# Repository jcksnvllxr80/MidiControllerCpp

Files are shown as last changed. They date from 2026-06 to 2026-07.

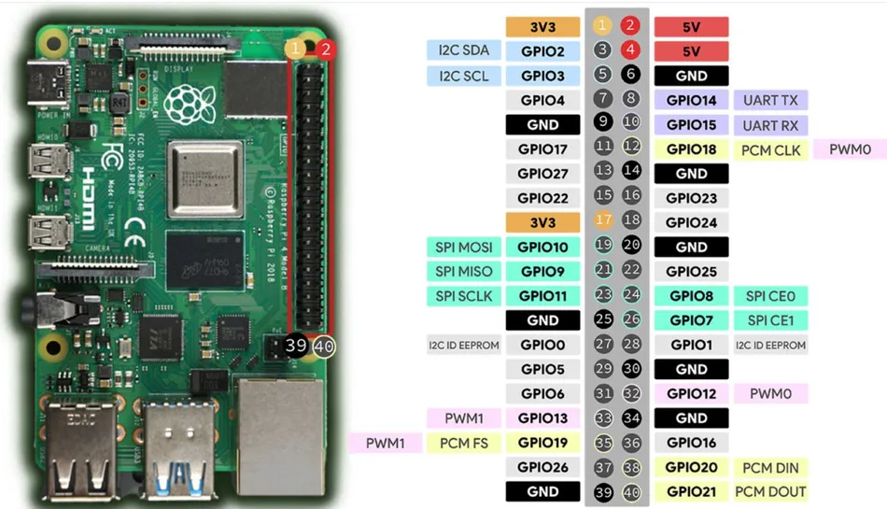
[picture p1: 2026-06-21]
docs/pi4_pinout.png

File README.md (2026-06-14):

# MidiController (C++)



Portable C++17 rewrite of a guitar-pedal MIDI controller's brain, ported from the
Raspberry Pi Python version. Hexagonal design: a hardware-free domain core with all
I/O behind interfaces, so the same code runs on the desktop sim now and a
microcontroller later.

Status: domain core + config + simulator are done and tested; the microcontroller
firmware (Pico 2 W / RP2350) builds and is under hardware bring-up. (The editor app
is a separate project.)
Roadmap: [docs/plan.md](docs/plan.md).

## Build, test, run (WSL)

The **firmware** builds with CMake + the Pico SDK; the **simulator** and the **tests**
build with `g++` (C++17) — GoogleTest and nlohmann/json are vendored, so the host
build has no other dependencies.

```sh
make build       # firmware  -> build-pico/midicontroller_pico.uf2  (Pico 2 W; needs PICO_SDK_PATH)
make build-sim   # simulator  -> build/midicontroller
make test        # build & run all tests (unit + mock + e2e)
make run         # run the simulator on data/ (scripted demo)
make clean       # remove desktop build/ ;  make pico-clean removes build-pico/
```

Flashing and wiring: [docs/mcu.md](docs/mcu.md) and [docs/wiring.md](docs/wiring.md).

## CI & releases

GitHub Actions ([`.github/workflows/ci.yml`](.github/workflows/ci.yml)) runs the host test
suite and builds the firmware `.uf2` on every push and PR. On a push to `master`, once both
pass, it cuts a GitHub **Release** `v<VERSION>` (from the [`VERSION`](VERSION) file) with the
versioned `.uf2` attached — **only when `VERSION` changed** (the tag is new). To ship: bump
`VERSION` and merge to `master`.

## Layout

```
include/mc/   headers: domain/ ports/ config/ adapters/ app/
src/          implementations + main.cpp
data/         config as JSON: midi_controller.json, pedals/, songs/, sets/
tests/        unit/ mock/ e2e/ support/
tools/        yaml2json.py (YAML→JSON), embed_data.py (bake data into flash), gen_font.py, gen_wiring_excalidraw.py
third_party/  vendored googletest + nlohmann/json
docs/         plan, architecture, domain, midi-protocol, config-format, mcu, wiring, wifi-app-handoff
```

## Notes

- The MIDI output matches the original Python byte-for-byte, including its quirks
  (e.g. `Set Preset`'s `cc:0` bank is never sent). See [docs/midi-protocol.md](docs/midi-protocol.md).
- `data/*.json` is generated from the original YAML by `tools/yaml2json.py` and committed.

## Docs

- [docs/architecture.md](docs/architecture.md) — ports & adapters + data-flow diagrams (mermaid)
- [docs/domain.md](docs/domain.md) — the core modules
- [docs/midi-protocol.md](docs/midi-protocol.md) — byte construction & dispatch
- [docs/config-format.md](docs/config-format.md) — JSON config reference
- [docs/mcu.md](docs/mcu.md) — firmware build/flash, adapters, hardware status
- [docs/wiring.md](docs/wiring.md) — Pico 2 W pin map, parts, power (+ `wiring.excalidraw` diagram)
- [docs/wifi-app-handoff.md](docs/wifi-app-handoff.md) — editor-app protocol contract (WiFi, device discovery, firmware update)

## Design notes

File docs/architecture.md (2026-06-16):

# Architecture

Ports & adapters (hexagonal). The domain core is pure C++ and depends only on
the **ports** (interfaces). Adapters implement the ports for a target; the
`Application` wires a concrete set of adapters to the core and runs the loop.

```mermaid
flowchart TB
    EXT["external editor (separate project)"] -- "USB / WiFi editor link" --> APP

    subgraph APP["app/ Application — composition root + event loop"]
      L["poll input → button/encoder handler → mutate state → display → emit MIDI"]
    end

    subgraph PORTS["ports/ (pure virtual HAL)"]
      direction LR
      IMidiOut & IDisplay & ILed
      IInput & IClock & IConfigStore & IConfigTransport
      IWifi & ISystemControl
    end

    subgraph SIM["adapters/sim (now)"]
      direction LR
      LMid["logging midi/led"] & CDisp["console display"]
      SInp["scripted input"] & CClk["chrono clock"] & FsCS["fs config store"]
    end

    subgraph MCU["adapters/mcu (Phase 3)"]
      direction LR
      EXP["MCP23017 footswitches (I²C) + encoder/LED GPIO"] & OLED["SSD1306 (SPI)"]
      DIN["MIDI → PIC bridge (I²C) → 6 jacks"] & STORE["FlashKv store + watchdog"]
      LINK["editor link: USB CDC + WiFi/mDNS :8080"]
    end

    subgraph CORE["domain/ (pure C++, no hardware, no JSON)"]
      direction LR
      MM["MidiMessage · Transform · Value"]
      PC["PedalConfig · MidiPedal"]
      SS["Setlist/Song/Part · ControllerState"]
      BM["ButtonSM · MenuTree"]
    end

    APP --> PORTS
    PORTS --- SIM
    PORTS --- MCU
    APP --> CORE
    CORE --> PORTS

    CFG["config/ConfigLoader\n(only JSON-aware module)"] --> CORE
    DATA[("data/*.json")] --> CFG
```

Data flow on a "load part":

```mermaid
sequenceDiagram
    autonumber
    participant U as Footswitch / Rotary (IInput)
    participant A as Application
    participant M as MenuTree
    participant P as MidiPedal (×N, channel order)
    participant Out as IMidiOut / IDisplay
    U->>A: InputEvent
    alt commit (Select / long-press / menu select)
        A->>P: turnOn/Off → setPreset → setParams
        P->>Out: exact CC/PC bytes
        A->>Out: song-info line
    else preview (Part/Song up/down)
        A->>Out: preview song-info line (no MIDI)
    else rotary
        A->>M: changeMenuPos / pressFor
        M->>Out: menu line
    end
```

> An `architecture.excalidraw` can be exported from the Mermaid above if a
> hand-editable canvas is wanted; the Mermaid here is the canonical source.

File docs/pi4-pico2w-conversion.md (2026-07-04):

# Pi 4 → Pico 2 W Conversion

The MidiController PCB is **unchanged**. This is a **driving-board swap**: the
Raspberry Pi 4 that used to plug into the board's 40-pin header (`J35`,
`Raspberry_Pi_2_3` in `PCB/MidiControllerPCB.sch`) is replaced by a Pico 2 W
(RP2350). The old ribbon now lands on a small adapter that routes each net to the
Pico GPIO below. **All wiring, buses, protocols, and the MCP23017 expander config
stay identical to the Pi** — the firmware just speaks the same three buses.

> **This supersedes an earlier draft of this doc that described a ground-up
> redesign** (native-GPIO footswitches, UART MIDI, an I²C OLED, a 6th footswitch,
> and "tempo pulse outputs"). None of that is on the real board — see the notes at
> the bottom.

## What actually crosses the ribbon

Only 14 signal lines (plus 3V3 / 5V / GND). Everything else lives behind the two
I²C peripherals on the board.

| Group | Signal | RPi 4 (BCM GPIO) | Pico 2 W (GP) | Goes to |
|---|---|---|---|---|
| **I²C bus** (shared) | SDA | GPIO2 | **GP4** | MCP23017 `0x22` + PIC `0x04` |
| | SCL | GPIO3 | **GP5** | same bus |
| **MCP interrupts** | INT A | GPIO4 | **GP2** | MCP23017 bank-A change |
| | INT B | GPIO17 | **GP3** | MCP23017 bank-B change |
| **OLED (SPI)** | SCLK | GPIO11 | **GP18** | SSD1306 |
| | MOSI | GPIO10 | **GP19** | SSD1306 |
| | CS | GPIO8 (CE0) | **GP17** | SSD1306 |
| | DC | GPIO12 | **GP20** | SSD1306 |
| | RST | GPIO25 | **GP21** | SSD1306 |
| **Rotary encoder** | Encoder A | GPIO24 | **GP14** | quadrature |
| | Encoder B | GPIO23 | **GP15** | quadrature |
| **RGB knob LED** | Red (PWM) | GPIO16 | **GP10** | knob LED |
| | Green (PWM) | GPIO20 | **GP11** | knob LED |
| | Blue (PWM) | GPIO21 | **GP12** | knob LED |
| **Power** | 3V3 | phys pin 17 | **3V3(OUT) pin 36** | net `VEE` → OLED supply (`J1`). (Pi pin 1, the other 3V3, is no-connect.) |
| | 5V | phys pin 2 | **VBUS pin 40** | net `VCC` → chip VDD + pull-ups — **see warning below** |

> ⚠️ **`VCC` (5 V) feeds more than "chip VDD + pull-ups" — it reaches six of
> the signal lines in the table above.** MCP23017 (`U2`) and the PIC bridge
> (`U10`) both run at `VCC` = 5 V, and so do: the I²C pull-ups (`R73`/`R74`
> on SDA/SCL), the MCP INT A/INT B push-pull outputs, and the rotary
> encoder's A/B pull-ups (`R29`/`R30`, confirmed in
> `pcb/midi-controller/MidiControllerPCB.net`). That means **GP4, GP5, GP2,
> GP3, GP14, GP15 all present 5 V to the Pico** and need level-shifting.
>
> **`VCC` stays at 5 V — it can't just be rewired to `3V3(OUT)`.** `U5` (a
> CD4050 hex buffer, powered from `VCC`) fans the PIC's MIDI output to all 6
> jacks, and MIDI's current-loop spec is nominally 5 V through 220 Ω
> resistors; dropping `VCC` to 3.3 V would weaken that drive for real MIDI
> gear. See [`wiring.md`](wiring.md) §1a for the level-shifter wiring (one
> 8-channel BSS138 module covers all 6 lines) and the full pin-by-pin
> breakdown. The encoder's RGB LED common is also tied to `VCC`,
> common-anode — not common-cathode as earlier drafts assumed.
| **Ground** (J35 GND pins) | GND | phys pin 6 | **GND pin 3** | board GND plane |
| | GND | phys pin 9 | **GND pin 8** | board GND plane |
| | GND | phys pin 14 | **GND pin 13** | board GND plane |
| | GND | phys pin 20 | **GND pin 18** | board GND plane |
| | GND | phys pin 25 | **GND pin 23** | board GND plane |
| | GND | phys pin 30 | **GND pin 28** | board GND plane |
| | GND | phys pin 34 | **GND pin 38** | board GND plane |
| | GND | phys pin 39 | **AGND pin 33** (tie to GND; ADC unused) | board GND plane |

The Pico-side assignments are the source of truth in
[`include/mc/adapters/mcu/Pins.h`](../include/mc/adapters/mcu/Pins.h); the BCM
column is what the adapter board maps each ribbon net **from**.

## What lives behind the buses (not on the ribbon)

- **5 footswitches + the rotary push button** are inputs on the **MCP23017 expander
  (`0x22`)**, read over I²C exactly as the Pi did (same IODIR/IPOL/GPINTEN/INTCON/
  GPPU/IOCON register values — see `McpExpander`). Expander bits: FSW1=A0, FSW2=A1,
  FSW3=A2, FSW4=B0, FSW5=B2, push button=B7 (the B7 selector is inverted via IPOL).
- **MIDI** is generated by writing raw bytes over I²C to the **PIC18F26K80 bridge
  (`0x04`)**, which fans every byte out to all **6 jacks: 2× DIN-5 + 4× TRS-MIDI**
  (`MIDI.py` did the same `writeRaw8`-per-byte). The Pico does **not** drive a MIDI
  UART, and the TRS jacks carry **MIDI**, not tempo.

## Key changes from the Pi

- **Form factor only.** The driver board changes (Pi 4 → Pico 2 W); the rest of the
  PCB, the expander, the PIC MIDI bridge, the OLED, the encoder, the LED, the
  footswitches, and all six MIDI jacks are untouched.
- The Pico has native USB for the editor link and on-board WiFi (CYW43); the Pi's
  network role is replaced by that.
- **The cooling fan is dropped.** It was driven by the Pi OS's temperature-based
  `gpio-fan` (set up in `raspi-config`), purely to cool the hot Pi 4 — not by the
  app, and not via any switching circuit on this PCB. The RP2350 runs cold and needs
  no active cooling, so there is no fan and no firmware fan control. Leave the `J2`
  fan header unpopulated.

## Corrections vs. the old "redesign" draft

For the record, so the redesign assumptions don't creep back in:

- **No 6th footswitch.** The board has 5 footswitches (plus the rotary push button).
- **No tempo/clock pulse outputs.** There is no GPIO-driven clock. The 4 TRS jacks are
  MIDI. Tempo on the Pi was set via menu/controls and is **display-only** (it was
  never even transmitted as MIDI — the only `TapTempo` reference was dead legacy code).
- **MIDI is over I²C to the PIC**, not native UART; **the OLED is SPI**, not I²C.

## Sources

- Pi 4: `MidiController/` — `Main/midi_controller.py`, `RotaryEncoder/RotaryEncoder.py`,
  `OledDisplay/OledDisplay.py`, `Footswitches/Footswitches.py`,
  `MCP23017_R1/MCP23017_R1.py`, `MIDI/MIDI.py`, `PCB/MidiControllerPCB.sch`
- PIC MIDI bridge: `MIDI_I2C_UART/` (I²C slave `0x04` → EUSART1 MIDI out)
- Pico 2 W: `include/mc/adapters/mcu/Pins.h`, `docs/wiring.md`

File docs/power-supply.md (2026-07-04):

# Power Supply — USB + Pedalboard 9V

The MIDI controller needs to run from two sources without conflict:

- **USB 5V** while programming/debugging the Pico from a PC.
- **Pedalboard 9V** (regulated down to 5V) during normal use on the board.

The Pico's power input is designed for exactly this. You don't switch between
sources — you OR them together so whichever is higher wins, with no
back-feeding.

## The Pico power pins

- **VBUS (pin 40)** — raw 5V straight from the USB connector.
- **VSYS (pin 39)** — main system input (1.8–5.5V). Feeds the onboard
  buck-boost SMPS that generates the 3.3V rail.
- On-board there is a **Schottky diode (D1) from VBUS → VSYS**. USB power
  reaches VSYS through ~0.3V of diode drop, but VSYS can never push current
  *back* into VBUS / the USB host.

That internal diode is the whole trick: mirror it for the external supply.

## Recommended circuit — two-diode OR into VSYS

```
   USB 5V ──[ internal D1 ]──┐
                             ├──► VSYS (pin 39) ──► SMPS ──► 3V3
9V→5V module ──[ ext Schottky ]─┘
                  │
   pedalboard GND ── common GND ── Pico GND (pin 38)
```

1. Regulate pedalboard **9V down to ~5V** with the module below.
2. Feed that 5V into **VSYS through a Schottky diode** (~0.3V drop, matches
   the internal D1).
3. Tie **grounds together** (pedalboard supply GND ↔ Pico GND).

VSYS then sits at roughly `max(VBUS − 0.3, Vext − 0.3)`. Whichever source is
higher powers the board; the lower one is reverse-blocked by its diode. USB can
be plugged in to program **while** the 9V is connected, with zero contention.

## The 9V → 5V module

**Breadboard: Recom R-78E5.0-1.0** — a synchronous buck regulator with the
inductor potted inside the package, so there's no separate magnetics part to
source or lay out. It's a **leaded, through-hole SIP-3 part** (TO-220-compatible
pin spacing, 2.54mm pitch) — plugs straight into a breadboard.

**PCB: MPM3610** — a synchronous buck regulator with the inductor built into
the package, so there's no separate magnetics part, no missing footprint to
chase down, and no FB-divider/inductor/extra-cap parts to place. It accepts up
to 21V in, comfortably covering the 9V pedalboard rail.

| Part | Breadboard | PCB |
|---|---|---|
| 9V→5V module | [Recom R-78E5.0-1.0](https://www.digikey.com/en/products/detail/recom-power/R-78E5-0-1-0/4930585) — SIP-3, THT, 5V/1A out, up to 28V in | [MPM3610GQV-Z](https://www.digikey.com/en/products/detail/monolithic-power-systems-inc/MPM3610GQV-Z/5292909) — QFN-20, 3×5×1.6mm, 5V/1.2A out, up to 21V in |
| OR-ing diode into VSYS | [1N5817-T](https://www.digikey.com/en/products/detail/diodes-incorporated/1N5817-T/22052) (DO-41, THT) | [SS14](https://www.digikey.com/en/products/detail/onsemi/SS14/965474) (SMA/DO-214AC) |

### PCB footprints (KiCad)

| Part | Package | KiCad footprint |
|---|---|---|
| MPM3610GQV-Z | QFN-20, 3×5×1.6mm | *No stock KiCad footprint* — download from [SnapEDA](https://www.snapeda.com/parts/MPM3610GQV-Z/MPS/view-part/) |
| SS14 diode | SMA / DO-214AC | `Diode_SMD:D_SMA` |

## Important details

- **Stay under 5.5V at VSYS.** 5V minus a Schottky drop ≈ 4.7V — well in
  range. Never feed 9V directly to VSYS.
- **Do NOT connect external 5V straight to VBUS.** That ties it to the USB 5V
  line and can back-feed the PC's USB port. Always enter via VSYS through the
  diode.
- **Pedalboard polarity:** many 9V pedal supplies are center-negative
  (Boss style) and daisy-chains can share ground unexpectedly. Ensure the
  module's input ground = output ground = Pico ground, and confirm jack
  polarity before wiring.
- **Current budget:** Pico + SPI OLED + MCP23017 (@0x22) + the I²C→MIDI PIC
  bridge (@0x04) is well under ~300mA — the MPM3610's 1.2A rating leaves
  plenty of headroom.

## Pedalboard Isolation (Strymon Ojai)

Audio noise on a pedalboard couples in through **shared ground and shared
supply**, not through the regulator topology. The Pico already has its own
switching SMPS onboard (the buck-boost making 3.3V), so the board is a
switching-noise source regardless of how the 5V is made. The defense is
**isolation**, and the supply for this build handles it:

- **Strymon Ojai** — five fixed **9V / 500 mA fully isolated** outputs off a
  24W brick (24V adapter). Each output is transformer-isolated, so its ground
  does **not** share copper with the audio pedals → no ground loop, no
  conducted hum path into the audio chain. (The 9-output **Zuma**, 48W, behaves
  identically if used instead.)
- **Use one dedicated isolated output** for the controller. **Do not
  daisy-chain** it with an audio pedal — keep them on separate windings.
- **Current:** controller draws ~300 mA → ~2.7W at the 9V input. Well under the
  500 mA per-output limit. Keep a running tally of all pedals so the board stays
  within the **24W total** budget.
- **Polarity:** Strymon outputs are **center-negative** 2.1mm barrel
  (Boss-standard). Wire the input jack as **tip = − / ground, sleeve = +9V**.
  Don't assume center-positive.

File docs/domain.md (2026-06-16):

# Domain model

The domain core is pure C++17 — no hardware, no JSON, no globals. Every module
maps to a piece of the original Python.

| C++ (`include/mc/domain`) | Ports from (Python) | Notes |
|---|---|---|
| `Value` | duck-typed `value` in EffectLoops | `variant<None, bool, long, string, EngagedRef>`. `EngagedRef{name, engaged}` is a song's `{name, engaged}` param value. |
| `MidiMessage` | `MIDI.py` | CC `[0xB0\|ch-1, cc, val]`, PC `[0xC0\|ch-1, prog]`. Channel→status math lives here, testable. |
| `Transform` | `EffectLoops.check_for_func` (`eval`) | Safe parser for `x <op> n` and `{...}.get(x, None)`. No `eval`. Unsupported expressions throw at load. |
| `PedalConfig` / `Action` | per-pedal YAML | Typed, recursive action tree. Group nodes (Engage, Set Preset, Knobs/Switches…) are the root `Action`'s children. |
| `MidiPedal` | `EffectLoops.MidiPedal` | `turnOn/Off`, `toggle`, `setPreset`, `setTempo`, `setParams`, `setSetting` + the dispatch (`determine_action_method` / `determine_parameter_method` / `convert_to_int` / `handle_multi`). Emits via `IMidiOut`. |
| `Setlist`/`Song`/`Part` | `PartSongSet.py` | Plain `std::vector` (the hand-rolled doubly-linked list is gone; prev/next is `index ± 1`). A `Part` holds, per pedal, `PedalState{engaged, preset, params, settings}`. |
| `ButtonSM` | `EffectLoops.ButtonOnPedalBoard` | Short (<0.5s) / long press; partner double-press (0.25s window). Time via `IClock`. |
| `ControllerState` | `midi_controller.yaml` | Current set/song/part, tempo, mode, knob colour/brightness, button lock, the channel→pedal table, the footswitch action map. |
| `MenuTree` | `N_Tree.py` + RotaryEncoder menu logic | The tree plus the rotary navigation engine and message formatting. Hardware-free: messages go to an injected sink, node behaviours are callbacks. |

## Deliberate differences from the Python

These are intentional, documented, and covered by tests.

- **Construction has no side effects.** Python's `MidiPedal.__init__` emitted
  engage + preset MIDI as a side effect of building the object. Here, building a
  pedal sends nothing; the `Application` drives every emission through
  `loadPart()`. Cleaner and deterministic.
- **Tempo is display-only, like the Pi.** The song BPM is shown on the OLED and
  never transmitted. Python *looked* like it sent tempo MIDI on part load, but only
  for a pedal named `TapTempo` — and no such pedal exists (legacy looper-era code),
  so it was dead. An early C++ draft added an `ITempoOut` pulse port for this; that
  was fiction (the board has no tempo jacks — the 4 TRS jacks are MIDI) and has been
  removed. `MidiPedal::setTempo()` remains as a faithful, unused mirror of the Python
  method.
- **No `eval`.** `Transform` is a fixed grammar; an unknown expression is a loud
  load-time error rather than a silently-evaluated lambda.
- **Menu select uses clean semantics.** The deep "edit a pedal's CC map" submenu
  (the densest, most device-specific Python) is not ported; the navigation engine
  that powered it *is*, and the Set/Song/Part/Knob/Lock menus are wired and
  tested.
- **Defaults persistence differs by target.** Python rewrote `midi_controller.yaml`
  on every part load. The firmware now does this too, but **debounced**: the current
  set/song/part are flushed via `Application::tick()` after ~1.5 s idle, so a flash
  write never lands mid-performance. The desktop sim deliberately does *not* persist,
  to avoid mutating the shared `data/` fixture.

See [`midi-protocol.md`](midi-protocol.md) for the byte-level dispatch and the
faithful quirks.

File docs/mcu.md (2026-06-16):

# Microcontroller target (Pico 2 W / RP2350)

Phase 3 adapters that run the same domain core on hardware. The desktop sim is
unchanged; only the adapters and the build system differ.

## Build & flash

Build the `.uf2` in WSL (same shell you run `make` in), then flash it to the
board. Because the repo lives on `C:\`, the built `.uf2` is also a normal Windows
file you can drag-and-drop.

### 1. One-time prerequisites (WSL / Ubuntu)

```sh
sudo apt update
sudo apt install -y cmake gcc-arm-none-eabi libnewlib-arm-none-eabi build-essential python3 git
# Pico SDK with pico2_w (RP2350) support — needs >= 2.1.0:
git clone --branch master --recurse-submodules https://github.com/raspberrypi/pico-sdk ~/pico-sdk
echo 'export PICO_SDK_PATH=$HOME/pico-sdk' >> ~/.bashrc && source ~/.bashrc
```

### 2. Build

```sh
cd /mnt/c/Users/A-A-Ron/git/MidiControllerCpp/MidiControllerCpp
cmake -B build-pico -DPICO_BOARD=pico2_w
cmake --build build-pico -j        # -> build-pico/midicontroller_pico.uf2
```
Or just **`make build`** from the repo root — it wraps the two commands above and
defaults `PICO_SDK_PATH` to `$HOME/pico-sdk` (override: `make build PICO_SDK_PATH=...`).
(`make build-sim` builds the desktop simulator instead; `make pico-clean` wipes `build-pico/`.)
The editor link (and debug output) run over the USB CDC automatically — no flag
needed. WiFi (CYW43 + lwIP + mDNS) is built in too (the board is `pico2_w`).
CMake runs `tools/embed_data.py` (needs Python 3) to bake `data/*.json` into flash;
exceptions are enabled (`PICO_CXX_ENABLE_EXCEPTIONS`) because the loader throws on bad
config — and `Application::setup()` catches that and falls back to a safe, still-reachable
shell so a corrupt config can't brick boot.

### 3. Flash

> **First flash on a fresh Pico 2 W: you must use the BOOTSEL button.** A blank board has
> no firmware yet to accept a software "reboot to bootloader", so the hardware bootloader
> (hold **BOOTSEL** while power-cycling) is the only way in the first time.

**BOOTSEL drag-and-drop (easiest on Windows):**

1. Hold the **BOOTSEL** button while plugging the Pico into USB (i.e. power-cycle it with
   the button held). It mounts as a drive named **RP2350**.
2. Drag `...\MidiControllerCpp\build-pico\midicontroller_pico.uf2` onto that drive
   in Explorer (or `cp build-pico/midicontroller_pico.uf2 /mnt/e/` to the drive
   letter it mounted as). It reboots and runs immediately.

**Alternative — picotool** (run on Windows; WSL needs `usbipd` USB pass-through):
```sh
picotool load -x build-pico/midicontroller_pico.uf2   # -x = run after loading
```

**After the first flash — no button needed.** Once this firmware is on the board it can
drop itself into BOOTSEL on command: send `{"op":"reboot_bootloader"}` over USB or WiFi and
it re-enumerates as the `RP2350` drive, then copy the `.uf2` as above. The editor app
(**MidiControllerControllerApp**, the separate UI repo) drives this from a button — see
[`wifi-app-handoff.md`](wifi-app-handoff.md) (Task 4) for the end-to-end update flow.

### 4. Connect / debug

The device enumerates as a USB serial port named **"MidiController"**. Both the
editor protocol and debug `printf` share that one CDC (the app's codec skips
non-JSON noise). Open the COM port at 115200 to watch traffic or talk to it
directly. The editor app connects via its **Serial** transport (not the USB-raw
one, which is a stub for CDC devices).

> Wire your hardware to match `include/mc/adapters/mcu/Pins.h`. See
> [`wiring.md`](wiring.md) for the full build — pin map, external parts, power, and a
> diagram ([`wiring.excalidraw`](wiring.excalidraw)). The build compiles clean and the
> **USB editor link is confirmed working on hardware** (over serial). **WiFi is
> compile-verified only** — not yet tested on a real network.

## Adapters (`include|src/adapters/mcu/`)

| Adapter | Port | Notes |
|---|---|---|
| `McuClock` | IClock | `time_us_64()` |
| `McuMidiOut` | IMidiOut | raw MIDI bytes over I2C to the PIC bridge @0x04 (writeRaw8 per byte); the PIC fans out to all 6 jacks |
| `McpExpander` | (helper) | MCP23017 @0x22 over I2C; configured byte-for-byte like the Pi (Footswitches.py); supplies the switch inputs |
| `McuLed` | ILed | 3-channel PWM; colour names match RgbKnob |
| `McuInput` | IInput | 5 footswitches + rotary push button read from `McpExpander` over I2C (INT-driven, reuses domain `ButtonSM`); quadrature encoder on native GPIO |
| `Ssd1306Display` | IDisplay | 128x64 SSD1306 over SPI (7-pin header: SCLK/MOSI/CS/DC/RST + power/GND); splits on " - " into rows |
| `McuConfigStore` | IConfigStore | reads config baked into flash; writes go to a RAM overlay, persisted via `FlashKv` |
| `FlashKv` | (persistence) | stores the write overlay in one reserved flash sector (`KvCodec`, host-tested) |
| `EditorProtocol` (app) | — | newline-JSON request/response; shared by the USB and WiFi links |
| `StdioConfigTransport` | IConfigTransport | runs `EditorProtocol` over the USB CDC |
| `WifiManager` | IWifi | CYW43 STA join, lwIP TCP server (same protocol) on `:8080`, mDNS, creds in flash |
| `McuSystemControl` | ISystemControl | `reboot` (app) / `reboot_bootloader` (USB BOOTSEL via `reset_usb_boot`); reset deferred so the editor ack flushes first |

Pin assignments live in one place: `include/mc/adapters/mcu/Pins.h` — edit to match your
wiring. The full build (pin map, external parts, power, diagram) is in [`wiring.md`](wiring.md).

## Status of the hardware-only pieces

These can't be compiled/flashed without the SDK + board, so they're marked by how
far they're verified:

- **OLED font** — DONE. Full ASCII 0x20–0x7E in `Ssd1306Font.h`, generated by
  `tools/gen_font.py` from the public-domain Adafruit GLCD font.
- **USB editor link** — DONE and **confirmed working on hardware** (over serial):
  `identify`/`ping`/`list_*`/`get_*`/`write_*`/`dpad`/`short`, plus `delete_set`/
  `delete_song`/`delete_pedal`/`delete_part` and `write_part` (via the new
  `IConfigStore::remove`; the flash store tombstones build-time-embedded entries
  since their blobs can't be erased). `write_part`/`delete_part` read-modify-write
  the song file (parts have no file of their own). Also `reboot_bootloader` (drops
  into USB BOOTSEL via `reset_usb_boot` — flash a `.uf2` with no front button) and
  `reboot`, both behind `ISystemControl`/`McuSystemControl` (the reset is deferred a
  few ms so the ack flushes first). `identify` now also returns a `device_id` (the
  RP2350 board id) so the editor can dedupe one unit seen over both USB and WiFi.
  A second **raw-USB** path was added (`-DMC_ENABLE_USB_EDITOR=ON`): a vendor-class
  interface (`usb/usb_descriptors.c` + `UsbConfigTransport`, bulk IN/OUT) with
  MS-OS-2.0 descriptors so Windows auto-binds **WinUSB**, for the host app's `nusb`
  transport. **Unverified on hardware** (the verified link is the default CDC build;
  select this variant with `-DMC_ENABLE_USB_EDITOR=ON`). Must match host
  `transport/usb.rs`: VID 0xCAFE/PID 0x4001, iface 0, EP OUT 0x01 / IN 0x81; stdio
  moves to UART in that build.
- **Flash persistence** — DONE (codec host-tested) and in use: WiFi creds *and* the
  "save defaults" (current set/song/part, written back debounced on change) persist
  via `FlashKv`. Erase/program now goes through `flash_safe_execute()` (XIP-safe;
  `PICO_FLASH_ASSUME_CORE1_SAFE=1` since core1 is never launched — falls back to an
  IRQ-masked write if the safe path is unavailable). Still one reserved 4 KB sector;
  large multi-file edits are a multi-sector follow-up.
- **Reliability** — DONE: an 8 s hardware **watchdog** (enabled after boot init, fed
  each main-loop pass) reboots on a hang; `Application::setup()` falls back to a safe
  shell on bad config; the WiFi connect/reconnect is non-blocking so it can't stall
  the loop under the watchdog; "save defaults" is debounced (1.5 s idle) so a part
  change mid-song doesn't fire an IRQ-masked flash write.
- **WiFi** — built and **compile-verified only (not network-tested)**. First-time
  setup is over USB (`wifi_set`); on boot it auto-joins the saved network
  (non-blocking) and **auto-reconnects** if the link drops, serves the same protocol
  over TCP `:8080`, and advertises via mDNS (`midicontroller.local` /
  `_midicontroller._tcp`). On/off via `wifi_enable`. The app side (a WiFi transport +
  "Set WiFi" UI) is specced in [`wifi-app-handoff.md`](wifi-app-handoff.md).
- **MCP23017 input + selector polarity** — the expander is configured exactly as the
  Pi did (`McpExpander`), but the INT-triggered read path and the selector's
  inverted-polarity decode are **compile-verified only** — confirm
  on hardware that all 5 footswitches and the rotary push button register.
- **MIDI over I2C** — bytes go to the PIC @0x04 like the Pi; **confirm on hardware**
  the bridge still fans out to the DIN + TRS jacks.
- **OLED over SPI** — transport rewritten from I2C to SPI (7-pin header); **confirm on hardware**.
- **On-target RAM check** — confirm the peak by parsing `BigSky.json` on device.

## Why RP2350 / Pico 2 W

520 KB RAM (vs RP2040's 264 KB) is what lets the build keep nlohmann/json
uncompromised: config is parsed one file at a time, peak is the largest pedal's
JSON DOM (~hundreds of KB worst case) which the 2 W absorbs comfortably. PIO,
dual M33 + FPU, and native USB cover MIDI timing and the host link.
Confirm the real RAM peak by parsing BigSky on-target once.

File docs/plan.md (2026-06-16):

# MidiController: Python → C++ Port

> **Hardware-model correction (supersedes parts of this roadmap).** This plan was
> written assuming a redesign that turned out not to match the real, fixed PCB. The
> truth, verified against the schematic and the Python source: **5 footswitches**
> (not 6) + a rotary push button, all on an **MCP23017 expander over I²C**; **MIDI
> goes over I²C to a PIC bridge (`0x04`)** that fans out to 6 jacks (2× DIN-5 +
> 4× TRS-MIDI — all MIDI, **no tempo jacks**); the **OLED is on SPI**. There is **no
> `ITempoOut`/tempo-pulse port** — tempo is display-only. The Pico 2 W is a
> **driving-board swap** onto the unchanged PCB. See
> [`pi4-pico2w-conversion.md`](pi4-pico2w-conversion.md) and [`wiring.md`](wiring.md);
> phase bullets below that mention "6 footswitches", "4 tempo outputs", `ITempoOut`,
> "native MIDI DIN", or "tap tempo" are obsolete.

## Context
The guitar pedal runs as Python on a Raspberry Pi 4: **5 footswitches**, an OLED, a rotary
knob (RGB LED + pushbutton), and MIDI out. The Pi is the "brain" (UI, song/preset state,
MIDI message building); the switches/push button are on an **MCP23017 expander (I²C)** and
a **PIC bridge (I²C `0x04`)** turns the Pi's MIDI bytes into the physical jacks (2× DIN-5 +
4× TRS-MIDI). A Java HTTP bridge (`piMidiHttp`) + a web app edit config files over WiFi.

Goal now: rewrite the **brain** in clean, portable C++ so it can later move to a
microcontroller (WiFi → USB). Get the C++ patterns right and fully tested first; hardware
comes later. This plan covers the firmware only; the controller/editor app is a separate project.

## Decisions (locked)
- **Firmware lives in** `C:\Users\A-A-Ron\git\MidiControllerCpp\MidiControllerCpp`. The controller/editor app is a separate project, out of scope here.
- **Config format: JSON.** One-time convert the existing YAML songs/sets/pedals to JSON.
- **Build/run: WSL + GoogleTest, plain Makefile.** Host: `make build-sim` / `make test` / `make run` (only needs `g++`). Firmware: `make build` → the Pico `.uf2` (needs the Pico SDK). Phase 1 had no real hardware — desktop/sim adapters only.
- **Architecture: ports & adapters (hexagonal).** Pure C++ domain core; all hardware behind interfaces. Same core runs on the sim now and the microcontroller later.
- **This plan is maintained in-repo** at `MidiControllerCpp/docs/plan.md` as the canonical, living roadmap — updated as each phase lands. The `~/.claude/plans/` copy is throwaway.

## Status (updated 2026-06-14)
- **Phase 1 — DONE.** Domain core (`MidiMessage`, `Value`, `Transform`, `PedalConfig`,
  `MidiPedal`, `Setlist/Song/Part`, `ButtonSM`, `ControllerState`, `MenuTree`), all 8
  ports, JSON config loaders, and the one-shot `tools/yaml2json.py` → committed `data/*.json`.
- **Phase 2 — DONE.** Sim adapters (`adapters/sim`), the `Application` event loop + `main.cpp`,
  and docs (`README.md` + `docs/{architecture,domain,midi-protocol,config-format}.md`).
- **Tests — ~850 passing** (unit + mock + e2e) via vendored GoogleTest/GoogleMock; `make build-sim`/`test`/`run`
  all green in WSL, zero warnings. Verification criteria 1–4 below are met. Coverage: a data-driven
  suite checks every reachable pedal param (representative values) through the real dispatch, plus
  per-module suites for MidiMessage/Value/Transform/PedalConfig/MidiPedal/SongPartSet/ControllerState/
  ButtonSM/MenuTree/ConfigLoader/FsConfigStore/sim adapters/Application, and per-part e2e flows.
- **Faithful-port decision:** observable MIDI is reproduced byte-for-byte, including the Python
  quirks (notably `Set Preset`'s `bank` uses `cc:0`, falsy in Python → bank select never sent;
  only the preset Program Change goes out). Documented in `docs/midi-protocol.md` and locked by tests.
- **Phase 3 (mcu) — builds clean, under hardware bring-up.** Target board: **Pico 2 W (RP2350)**.
  `adapters/mcu/` + the Pico `CMakeLists.txt` + `tools/embed_data.py` build a ~1.5 MB `.uf2` (`make build`);
  the core is MCU-ready (`Transform`'s `std::regex` is a hand parser; nlohmann/json is kept — the RP2350's
  520 KB RAM affords it). All adapters, WiFi (CYW43 + lwIP + mDNS) with non-blocking auto-reconnect,
  `FlashKv` persistence via `flash_safe_execute`, an 8 s watchdog, a boot-config guard, debounced
  "save defaults", the full OLED font, and the editor protocol (incl. `delete_*`/`write_part`,
  `reboot`/`reboot_bootloader`, `device_id`) are **compile/link-verified**. The **USB serial editor
  link is confirmed on hardware**; WiFi and the physical I/O are not yet bench-tested. See `docs/mcu.md`.

## What it does (so the model is clear)
Data model: **Setlist → Songs → Parts**. A Part stores, per pedal, `(engaged, preset, params, settings)`. Loading a Part sends MIDI to set every pedal's on/off + preset (+ tempo). A **MidiPedal** has a name, a MIDI channel (1–16), and a per-pedal command map that turns high-level actions (Engage, Bypass, Set Preset, Set Tempo, knob/param tweaks) into MIDI CC/PC bytes. Footswitches step parts/songs; the rotary knob drives a menu for editing.

## Architecture
```
        USB IConfigTransport  (external editor — separate project)
                 │
        ┌────────▼─────────┐
        │   Ports (HAL)    │  IMidiOut IDisplay ILed
        │   interfaces     │  IInput IClock IConfigStore IConfigTransport
        └───┬──────────┬───┘
   adapters │          │ adapters
   ┌────────▼───┐  ┌───▼──────────┐
   │ sim/desktop│  │ mcu (Phase3) │
   └────────────┘  └──────────────┘
        ▲
   ┌────┴───────────────────────────────────┐
   │ Domain core (pure C++, no hardware)     │
   │ MidiPedal · Transform · Setlist/Song/   │
   │ Part · ControllerState · ButtonSM ·     │
   │ MenuTree · MidiMessage                  │
   └─────────────────────────────────────────┘
```

## Target layout (`MidiControllerCpp/`)
```
include/           public headers (mirror src)
src/
  domain/          MidiMessage, MidiPedal, PedalConfig, Transform,
                   Setlist/Song/Part, ControllerState, ButtonSM, MenuTree
  ports/           IMidiOut, IDisplay, ILed, IInput, IClock, IConfigStore,
                   IConfigTransport, IWifi, ISystemControl  (pure virtual)
  config/          JSON loaders -> domain objects
  adapters/sim/    console display, scripted input, fs config store, chrono clock, logging midi
  adapters/mcu/    Pico 2 W: MCP23017 footswitches (I²C), SPI OLED, I²C MIDI bridge, encoder+LED GPIO, FlashKv, WiFi, USB editor link
  app/             Application (composition root + event loop)
  main.cpp
data/              converted JSON: midi_controller.json, songs/, sets/, pedals/
tests/             unit/, mock/, e2e/ + fixtures
docs/              plan.md (this roadmap), architecture.md (mermaid), domain.md, midi-protocol.md,
                   config-format.md, mcu.md, wiring.md (+ wiring.excalidraw), wifi-app-handoff.md
third_party/googletest   (vendored submodule, built by Makefile)
tools/             yaml2json.py (YAML→JSON), embed_data.py (bake → flash), gen_font.py, gen_wiring_excalidraw.py
Makefile
```

## ~~Phase 1 — Domain core + config (the actual conversion)~~ ✅ done
Build the pure-C++ core. Python source → C++ target:

| C++ module | Ports from | Notes |
|---|---|---|
| `MidiMessage` | `MIDI.py` | Builds CC `[0xB0|ch-1, cc, val]` / PC `[0xC0|ch-1, prog]`. Channel→status math lives here (testable), not in the adapter. |
| `Transform` | `EffectLoops.check_for_func` (`eval('lambda x: ...')`) | Replace `eval` with a tiny safe parser for `x <op> n`, op ∈ `+ - * / %`. Covers the only real cases (`x / 128`, `x % 128`). |
| `PedalConfig` | per-pedal YAML (`TimeLine.yaml`…) | Parsed map: Engage/Bypass/Toggle/Set Preset/Set Tempo/Knobs-Switches/Parameters. Each action = cc|pc|multi + optional transform, `dict` (name→int), `min`/`max`, `on`/`off`. |
| `MidiPedal` | `EffectLoops.MidiPedal` | `turnOn/Off`, `toggle`, `setPreset`, `setTempo`, `setParam(s)`, `setSetting`. Same dispatch as `determine_action_method` / `convert_to_int` / `handle_multi_functions`. |
| `Setlist/Song/Part` | `PartSongSet.py` | Plain `std::vector` (drop the hand-rolled doubly-linked list; keep prev/next via index). Part = `map<pedalName, PedalState>`. |
| `ButtonSM` | `EffectLoops.ButtonOnPedalBoard` | Short (<0.5s)/long press; partner double-press 0.25s window. Time via `IClock` so it's testable. |
| `ControllerState` | `midi_controller.yaml` | current setlist/song/part, tempo, mode, knob color/brightness, buttons_locked. |
| `MenuTree` | `N_Tree.py` + `RotaryEncoder.py` menu logic | The messiest port. Rotary CW/CCW navigation + select/long-hold thresholds. Port the tree + actions; isolate from hardware. |
| `config/*` | `setup()` in `midi_controller.py` | Load JSON → build pedals/state/songs. |

Ports defined this phase (headers only, sim impls in Phase 2): `IMidiOut`,
`IDisplay`, `ILed`, `IInput`, `IClock`, `IConfigStore`, `IConfigTransport`.

Data: run `tools/yaml2json.py` once to convert all existing YAML (songs, sets, pedals,
`midi_controller.yaml`) into `data/*.json`; commit the JSON. JSON lib: vendor a single
header (e.g. `nlohmann/json`) now; swap to a tiny MCU-friendly parser in Phase 3.

## ~~Phase 2 — Simulator, event loop, e2e, docs~~ ✅ done
- **Sim adapters** (`adapters/sim/`): console/stdout display, scripted-or-keyboard input, `std::filesystem` config store, `std::chrono` clock, a MIDI adapter that logs messages.
- **Application** (`app/`): wires ports+adapters and runs the event loop — port of `main()`/`setup()`. Poll input → button/encoder handler → mutate state → update display → emit MIDI. Replaces the Flask loop.
- *(An early draft added an `ITempoOut` pulse port here; it was later removed — the board has no tempo jacks and tempo is display-only. See the banner at the top.)*
- **Docs**: `architecture.excalidraw` (the diagram above), root `README.md` (build/test + layout, mermaid sequence of the event loop), short `domain.md`, `midi-protocol.md`, `config-format.md`. Concise — only what must be understood.

## Phase 3 — Microcontroller (in progress — Pico 2 W / RP2350)
Swap in `adapters/mcu/` to drive the **unchanged PCB** (driving-board swap, not a redesign): MCP23017 footswitches + rotary push button over I²C (`McpExpander`), native-GPIO encoder/LED, SSD1306 over **SPI**, MIDI as raw bytes over **I²C to the PIC bridge `0x04`** (which fans out to the 6 jacks), flash `IConfigStore`, and **USB `IConfigTransport`**. Core and tests stay unchanged — that's the payoff of the HAL.

Done (compile/link-verified, `make build` → `.uf2`): all adapters (`McuClock/McuMidiOut/McpExpander/McuLed/McuInput/Ssd1306Display/McuConfigStore/FlashKv/StdioConfigTransport`), `Pins.h`, `main_mcu.cpp`, the Pico `CMakeLists.txt` (board `pico2_w`, exceptions on), and `tools/embed_data.py`. Added beyond the original scaffold: **WiFi** (`WifiManager` — CYW43 STA + lwIP TCP `:8080` + mDNS, the same `EditorProtocol`, non-blocking auto-reconnect), the full OLED font (`tools/gen_font.py`), `FlashKv` persistence via `flash_safe_execute` (WiFi creds + debounced "save defaults"), an 8 s **watchdog**, a boot-config guard, editor-protocol `delete_*`/`write_part` + `reboot`/`reboot_bootloader` + `device_id` (`ISystemControl`/`McuSystemControl`), and the raw-USB/WinUSB link (`-DMC_ENABLE_USB_EDITOR`). `std::regex` removed from `Transform`. The desktop Makefile excludes `src/adapters/mcu/`; SDK-free MCU logic (codec, config store) is host-tested.

TODO before it ships: bench-test the physical I/O (MCP23017 footswitches + selector polarity, encoder, SPI OLED, I²C MIDI to the PIC, LED) and WiFi on a real board; an on-target RAM check parsing BigSky; the deferred on-device features (deep "Midi Pedals" editor menu, favourite mode, footswitch partner combos, About/IP screen); and a deliberate later pass on WiFi at-rest cred scrambling + wire auth/TLS. See `docs/mcu.md`.

## Tests (GoogleTest / GoogleMock)
- **Unit** (`tests/unit/`): `Transform` parse+eval; `MidiMessage` byte exactness; `convert_to_int`/dict/min-max/on-off; Setlist/Song/Part JSON load; `ButtonSM` short/long/partner with a fake clock; `MenuTree` navigation; config loaders.
- **Mock** (`tests/mock/`): `MidiPedal` against `MockMidiOut` — assert the **exact** CC/PC byte sequence for engage/bypass/preset (incl. `multi` bank+preset = `x/128` then `x%128`)/tempo/param. `ButtonSM` against `MockClock`. `Application` against mock display/input — assert display text.
- **E2E** (`tests/e2e/`): drive `Application` with scripted input + fake clock + the **converted real** fixtures (a setlist with real pedals). Assert the MIDI output sequence and display messages across: load setlist → next/prev part → next song → menu edit. This is the in-process equivalent of the old Flask `short`/`long`/`dpad` endpoints.

## Build (Makefile, run in WSL)
- `make build` — build the Pico firmware `.uf2` (CMake + Pico SDK; see `docs/mcu.md`).
- `make build-sim` — compile core + sim into a `midicontroller` binary.
- `make test` — build & run all GoogleTest suites (gtest/gmock compiled from vendored `third_party/googletest`).
- `make run` — launch the sim.
- `make clean` / `make pico-clean` — remove the desktop `build/` / firmware `build-pico/` artifacts.
Toolchain: `g++` (C++17), no apt deps beyond a compiler — googletest and the JSON header are vendored.

## Key risks / explicit decisions
- **`eval` → `Transform`**: arbitrary Python lambdas become a fixed safe grammar. If a pedal config ever needs an unsupported expression, the loader errors loudly rather than guessing.
- **Menu tree** is the densest Python logic — port it behind tests first, with `MenuTree` fully hardware-free.
- **MIDI channel math** stays in the domain so output is verifiable without hardware.
- **MIDI on the MCU** goes over I²C to the PIC bridge (`0x04`), paced at the MIDI byte rate so the bridge's 8-byte UART FIFO can't overrun. (Tempo is display-only — there is no tempo-output port; see the banner.)

## Verification
1. `make build-sim` succeeds in WSL.
2. `make test` — all unit/mock/e2e suites green; mock tests prove exact MIDI bytes match the Python behavior for real pedal configs.
3. `make run` — sim boots from `data/`, scripted footswitch/encoder input changes parts/songs and logs the expected MIDI + display text.
4. Spot-check: converted `data/*.json` round-trips the same pedal/preset/tempo state the Pi used (`midi_controller.yaml` → `midi_controller.json`).

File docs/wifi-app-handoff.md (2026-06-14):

# Handoff: add WiFi support to the controller app

**Audience:** an agent working in `MidiControllerControllerApp` (Tauri + Svelte UI,
Rust backend). The **firmware** WiFi side is done (see this repo); the app needs a
matching **WiFi transport** + a **"Set WiFi" UI**. The wire protocol is unchanged —
WiFi carries the exact same newline-JSON the serial transport already speaks, so
you reuse `protocol/codec.rs` verbatim.

## What the firmware already does

- Stores WiFi credentials in flash; on boot, if enabled, joins the saved network
  (non-blocking) and **auto-reconnects** if the link later drops — no reboot needed,
  so the app's TCP transport should simply retry the connection after a blip.
- Runs the **same** request/response protocol over **TCP on port 8080** (in
  addition to USB serial).
- Advertises via **mDNS**: hostname `midicontroller.local`, service
  `_midicontroller._tcp` on port 8080, TXT `version=1`.
- Adds three ops (work over USB *and* TCP):

  ```jsonc
  // set credentials (first-time setup, done over USB) — enables WiFi + connects
  -> {"id":N,"op":"wifi_set","ssid":"MyNet","password":"secret"}   // password optional (open net)
  <- {"id":N,"ok":true,"data":{"enabled":true,"connected":true,"ssid":"MyNet","ip":"192.168.1.50"}}

  // query status
  -> {"id":N,"op":"wifi_status"}
  <- {"id":N,"ok":true,"data":{"enabled":bool,"connected":bool,"ssid":"...","ip":"..."}}

  // turn WiFi on/off (persisted)
  -> {"id":N,"op":"wifi_enable","on":false}
  <- {"id":N,"ok":true,"data":{...status...}}
  ```

## First-time setup flow (UX)

1. User connects over **USB/Serial** (already works).
2. App shows a **"WiFi" screen**: SSID + password fields → on save, send `wifi_set`.
3. Show the returned `ip` (the OLED shows it too). Device is now on the network.
4. Next launch (or after a rescan), the **WiFi transport discovers it via mDNS**
   and the user can connect wirelessly — no cable.

## Firmware protocol contract (what's actually implemented)

So you don't have to infer it from the firmware source — this is exactly how the
device behaves, on **both** the USB serial link and the WiFi TCP link (identical
framing).

**Framing**
- One JSON object per line, `\n`-terminated. Requests carry an `id`; the firmware
  echoes it in the response.
- Success: `{"id":N,"ok":true,"data":<op-specific>}` (no `error`). `data` is
  omitted for ops that have no payload.
- Failure: `{"id":N,"ok":false,"error":"<message>"}` (no `data`).
- The firmware **ignores blank / non-JSON lines** (debug `printf` shares the same
  USB CDC), so a reader must skip non-matching lines — exactly what `codec.rs`
  already does.
- USB: 115200 8N1, device product string "MidiController". WiFi: TCP `:8080`,
  **one client at a time**. Same JSON framing on both.

**Ops the firmware answers** (`op` → request fields → `data` returned):

| `op` | request fields | `data` on success | notes |
|---|---|---|---|
| `identify` | — | `{"name","firmware","protocol_version","device_id"}` | confirm a device; `device_id` is a stable per-unit id (RP2350 board id) for USB/WiFi dedupe |
| `ping` | — | *(none)* | heartbeat |
| `list_sets` / `list_songs` / `list_pedals` | — | array of name strings | |
| `get_set` / `get_song` / `get_pedal` | `name` | that file's JSON object | the stored config, verbatim |
| `write_set` / `write_song` / `write_pedal` | `name`, `data` | *(none)* | persists to flash |
| `delete_set` / `delete_song` / `delete_pedal` | `name` | *(none)* | removes that file (idempotent) |
| `write_part` | `song`, `part`, `data` | *(none)* | splices one part into the song file (tempo + other parts preserved) |
| `delete_part` | `song`, `part` | *(none)* | removes one part from the song file |
| `dpad` | `direction` = `up`\|`down`\|`CW`\|`CCW` | `{"display_message": "..."}` | drives the menu/encoder; string is the OLED text |
| `short` | `button` = `"1"`..`"5"` | `{"display_message": "..."}` | footswitch action (1 PartDn, 2 Select, 3 PartUp, 4 SongDn, 5 SongUp) |
| `wifi_set` | `ssid`, `password` (optional) | `{"enabled","connected","ssid","ip"}` | saves creds, enables, connects |
| `wifi_status` | — | `{"enabled","connected","ssid","ip"}` | |
| `wifi_enable` | `on` (bool) | `{"enabled","connected","ssid","ip"}` | persisted on/off |
| `reboot_bootloader` | — | *(none)* | acks, then ~100 ms later resets into USB BOOTSEL (mass storage) to accept a `.uf2` — no front button |
| `reboot` | — | *(none)* | acks, then reboots into the application |

**Editing semantics (parts live inside songs).** There are no per-part files, so
`write_part` / `delete_part` do a read-modify-write of `songs/<song>.json`: the
firmware loads the song, splices/removes the named part, and writes the whole song
back (tempo and the other parts are preserved). `delete_*` is idempotent — deleting
a missing key still returns `ok:true`. On the device, deleting a build-time-embedded
config tombstones it (the embedded blob can't be physically erased), and a later
`write_*` of the same name brings it back.

> **MCU caveat:** on-device persistence currently uses one 4 KB flash sector for the
> write overlay. Small edits (a part, the current set/song/part, WiFi creds) are fine;
> persisting several *large* (~20–30 KB) song/pedal edits at once can exceed that
> sector and silently no-op the save. Multi-sector flash is a known follow-up. (The
> committed/embedded config is regenerated from `data/` at build time regardless.)

## Task 1 — WiFi transport (`src-tauri/src/transport/wifi.rs`)

Implement `Transport` (see `transport/mod.rs`) for `Protocol::Wifi`, mirroring
`serial.rs` but over TCP:

- `discover()` — browse mDNS for `_midicontroller._tcp` (crate suggestion:
  `mdns-sd`). For each hit, build a `DeviceInfo { protocol: Wifi, name, address:
  Address::Net { host, port }, .. }` (resolve to the IP or use `midicontroller.local`).
- `connect(device)` — `TcpStream::connect((host, port))`, set read timeout
  (~1500 ms), then run the **identify** handshake using the existing
  `codec::roundtrip` (TcpStream is `Read + Write`, so `codec` works unchanged).
  Return the `DeviceIdentity` from `data` exactly like serial.
- `request(req)` — `codec::roundtrip` over the stream.
- `disconnect()` / `is_connected()` — as in serial.
- Register it in `transport/registry.rs` alongside Serial/USB.

Because `codec.rs` is transport-agnostic (`Read`/`Write`), this is essentially
`serial.rs` with `TcpStream` swapped in for the serial port + mDNS discovery.

## Task 2 — "Set WiFi" UI (Svelte)

- A small form (SSID, password) reachable once connected over any transport.
- On submit: `request({op:"wifi_set", ssid, password})`; show
  `data.ip` / `data.connected`. Add a toggle that sends `wifi_enable {on}`.
- Optional: a `wifi_status` poll to reflect connection state.

## Task 3 — device discovery & filtering (show only MidiControllers)

The device list must contain **only** MidiControllers — over **both** USB/serial and
WiFi — and never random serial/USB gear. Discover on both transports, confirm with
`identify`, dedupe by `device_id`.

**USB / serial.** Enumerate serial ports; `serialport-rs` gives `UsbPortInfo { vid, pid,
product, manufacturer, serial_number }`. Cheap pre-filter (no I/O — never poke unknown
devices):
- **CDC build (default):** keep ports where `vid == 0x2E8A` (Raspberry Pi) **and**
  `product == "MidiController"` (manufacturer is also "MidiController"). Rejects non-Pico
  devices (other VID) and other Pico projects (other product string).
- **Raw-USB build (`MC_ENABLE_USB_EDITOR`):** keep `vid == 0xCAFE && pid == 0x4001`.

**WiFi.** Browse mDNS for `_midicontroller._tcp` (e.g. crate `mdns-sd`). Every hit is
already a MidiController (only this firmware advertises that service) — resolve host+port
and treat it as a candidate; no metadata pre-filter needed.

**Confirm (authoritative, both transports).** Open each *candidate* and send
`{"op":"identify"}`; keep it only if it replies `{"ok":true,"data":{"name":
"MidiController","protocol_version":N,"device_id":"…"}}`. Only probe pre-filtered/mDNS
candidates — don't blast `identify` at arbitrary serial ports (it can disrupt other gear).

**Dedupe.** The same physical unit can appear on USB *and* WiFi at once. Key the list by
`device_id` (the RP2350 board id — identical on both links) and merge into one entry. Two
*different* units have different `device_id`s even though both report `name ==
"MidiController"`, so `device_id` is also how you tell units apart.

## Task 4 — firmware update without the BOOTSEL button

The firmware drops itself into the UF2 bootloader on command (over USB *and* WiFi), so
users never touch the board:

1. App sends `{"op":"reboot_bootloader"}`. Firmware replies `{"ok":true}` and ~100 ms
   later resets into BOOTSEL. **Expect the serial/TCP connection to drop right after the
   ack** — that's success, not an error; tear the transport down cleanly.
2. ~1 s later a USB **mass-storage** drive appears: `vid == 0x2E8A`, `pid == 0x000F`
   (RP2350; RP2040 is `0x0003`), volume label **`RP2350`**. In this state it's
   indistinguishable from any RP2350 in BOOTSEL — present it as "RP2350 bootloader —
   ready to flash".
3. Copy `midicontroller_pico.uf2` onto that drive (a plain file copy flashes it), or shell
   out to `picotool load -x firmware.uf2`. The board reboots into the new firmware and
   re-appears in the list with the same `device_id`.
4. `{"op":"reboot"}` is a soft restart into the app (no flashing) — handy after a config
   change or to recover.

> Over WiFi, `reboot_bootloader` still drops the device into USB mass-storage mode, so the
> actual `.uf2` delivery needs a USB cable. The remote command is still useful to *prep*
> a cabled flash, but don't promise wireless flashing.

## Acceptance

- Set credentials over USB → firmware reports an IP.
- The app's WiFi scan lists the device (via mDNS) and connects to it over TCP.
- All existing ops (`list_*`, `get_*`, `dpad`, `short`, …) work identically over
  WiFi — same `codec`, just a different socket.
- The device list shows the MidiController over USB **and** over WiFi, deduped to one
  entry by `device_id`, and shows nothing else that's plugged in.
- "Update firmware" sends `reboot_bootloader`; the device re-appears as an `RP2350`
  drive and copying `midicontroller_pico.uf2` flashes it; it returns with the same
  `device_id`.

## Gotchas

- Same framing/codec as serial — do **not** invent a new protocol.
- Port is **8080**, service `_midicontroller._tcp`, host `midicontroller.local`.
- The firmware also answers `identify`/`ping` over TCP, so reuse the serial
  connect/heartbeat logic.
- `Protocol::Wifi` already exists in `transport/mod.rs`; `usb.rs` is a stub — model
  the new `wifi.rs` on `serial.rs`, not `usb.rs`.

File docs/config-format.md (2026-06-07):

# Config format (JSON)

The firmware reads JSON. `tools/yaml2json.py` converts the original Python YAML
1:1 (preserving key order — `set_params` emits in declaration order, so the
loader uses `nlohmann::ordered_json`). Files live under `data/`:

```
data/midi_controller.json     device state + channel table + footswitch map
data/pedals/<Pedal>.json      one pedal's command map
data/songs/<Song>.json        a song: parts -> pedals -> state
data/sets/<Set>.json          an ordered list of song names
```

## `midi_controller.json` → `ControllerState`

```jsonc
{
  "button_setup": { "1": {"function":"Part Dn","long_press_func":"Select Part Dn"}, ... },
  "controller_api": {"buttons_locked": false, "port": 8090},
  "current_settings": {"mode":"standard", "preset":{"setList":"...","song":"...","part":"..."}, "tempo":106},
  "knob": {"color":"Yellow", "brightness":"100"},
  "midi": {"channels": {"1": {"name":"QuartzV2","state":true,"preset":{"number":2}}, "6": null, ... }}
}
```

Null channels are dropped; channels load in ascending order. A channel preset is
`number` if present, else `name` (so `{"name":"Plexi"}` is a name-based preset).

## `pedals/<Pedal>.json` → `PedalConfig`

The top-level keys are **groups**: `Engage`, `Bypass`, `Toggle Bypass`,
`Set Preset`, `Set Tempo`, `Knobs/Switches`, `Parameters`. Each group is an
**action node**; nested maps become child action nodes.

Recognised leaf keys on an action node:

| key | meaning |
|---|---|
| `cc` | CC number (note: `0` is treated as "absent" — see midi-protocol.md) |
| `program change` / `control change` | sub-action `{func?, min?, max?, options?}` |
| `multi` | `{ "1": "child", "2": "child" }` — ordered sub-actions to run |
| `func` | a `Transform` expression (below) |
| `dict` | name→int map (param value lookup) |
| `value`, `on`, `off`, `press`, `release`, `min`, `max` | scalar leaves |
| `notes`, `display`, `options` | metadata (ignored by the MIDI core) |

Any other key is a **named child** (e.g. `bank`/`preset` under `Set Preset`, or
each knob under `Knobs/Switches`).

### `Transform` grammar (replaces `eval`)

Only two shapes are accepted (anything else throws at load):

1. **Arithmetic** — `x <op> n`, `op ∈ + - * / %`. Integer division/modulo (Python-2
   semantics for the non-negative MIDI values used). e.g. `"x % 128"`.
2. **Dict lookup** — `{"Key": int, ...}.get(x, None)`; a missing key yields
   "None" (nothing sent). e.g. ScarlettLove preset selection.

## `songs/<Song>.json` → `Song`

```jsonc
{
  "name": "Victory - Rhythm",
  "tempo": 110,
  "parts": {
    "Chorus": {
      "position": 1,
      "pedals": {
        "TimeLine":     {"engaged": false, "preset": 2},
        "ScarlettLove": {"engaged": true,  "preset": "Plexi"},
        "SuperSwitcher":{"preset": 1, "params": {"Loop 1": {"name":"Morning Glory","engaged":false}, ...}},
        "Iridium":      {"engaged": true, "preset": 1, "params": null}
      }
    }
  }
}
```

Parts are ordered by `position`. A pedal preset may be an int or a name string;
an absent preset is a no-op. `params` is an ordered map of `name → value`, where
a value is a scalar, a string, or `{name, engaged}` (only `engaged` affects
MIDI). `null`/absent `params` means none.

## `sets/<Set>.json` → `Setlist`

```jsonc
{ "name": "2017-05-22 Set", "songs": ["Victory - Rhythm", "Here As In Heaven - Lead", ...] }
```

Songs load in listed order; each name resolves to `songs/<name>.json`.

## Re-running the converter

```sh
python3 tools/yaml2json.py [SRC_DIR] [DEST_DIR]
# SRC_DIR defaults to the original Python project; DEST_DIR defaults to ./data
```

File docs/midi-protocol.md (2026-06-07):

# MIDI protocol & dispatch

How a high-level action becomes exact MIDI bytes. This mirrors
`EffectLoops.MidiPedal` in the original Python, including a few load-bearing
quirks the tests lock in.

## Byte construction (`MidiMessage`)

- **Control Change:** `[0xB0 | (channel-1), cc, value]`
- **Program Change:** `[0xC0 | (channel-1), program]`

Channel is 1..16. Example: TimeLine is on channel 2, so engage (`cc:102`,
`value:127`) is `B1 66 7F`.

## `determine_action_method` (engage / bypass / toggle / set preset / set tempo)

Given an action node and a value (defaulting to the node's `value`):

1. **`cc` present and non-zero** → `value = func(value)`; send `CC(cc, value)`.
2. else **`program change`** → `value = func(value)`; send `PC(value)`.
3. else **`control change`** → `value = func(value)`; send `CC(value, 127)` —
   the computed value is the CC *number*, the data byte defaults to 127.
4. else **`multi`** → run each named sub-action in order (below).

The `func` is the node's `Transform` (identity if none).

### Quirk 1 — `cc: 0` is falsy

Step 1 says "non-zero" because Python's `if action_dict.get('cc'):` treats `0`
as falsy. The "Set Preset → bank" sub-action is `{cc: 0, func: "x / 128"}`, so
**the bank select CC is never sent** — only the `preset` Program Change goes out.
We reproduce this exactly (`Action::hasTruthyCc()`), so presets ≤ 127 work and
the bank byte is omitted just like on the real rig.

### Quirk 2 — `multi` mutates the threaded value

`handle_multi` threads one `val` through every sub-action and reassigns it each
step. For TimeLine's `Set Preset` the bank is skipped (Quirk 1), so `preset`
sees the original value and sends `PC(value % 128)`. For QuartzV2's `Set Tempo`
(`hundreds: x/100` then `tens_ones: x%100`, both `cc:94`), the second step
operates on the **already divided** value — so tempo 110 sends `CC#94=1` then
`CC#94=1`, not `1` then `10`. Faithful to the Python; locked by a test. (Tempo is
never actually triggered on the rig — no pedal is named `TapTempo` — so this is
latent, but preserved.)

## `determine_parameter_method` + `convert_to_int` (knob/param tweaks)

Params (`Knobs/Switches`, `Parameters`) only fire when `cc` is non-zero. The
value is resolved by `convert_to_int`, in this order (matching Python):

1. a direct `on`/`off`/`press`/`release`/`value` key, or a `dict` entry → that int
2. `value == v` → `int(v)`
3. a bool (`EngagedRef` collapses to its `engaged` flag) → `on` / `off`
4. an int within `[min, max]` → itself (out of range → not sent)

Example: SuperSwitcher `Loop 1` is `{cc:102, on:127, off:0}`; a song's
`{name:"Morning Glory", engaged:false}` → `CC#102 = 0`.

## Per-part emission order

`Application::loadPart()` iterates pedals **in channel order** (QuartzV2=1,
TimeLine=2, Iridium=3, BigSky=4, SuperSwitcher=5, ScarlettLove=16), and per pedal
does engage/bypass → preset → params → settings. `tests/e2e` pins the full
sequence for a real part:

```
B0 61 00   QuartzV2 preset 0
B1 66 00   TimeLine bypass        C1 02   TimeLine preset 2
B2 66 7F   Iridium engage         C2 01   Iridium preset 1
B3 66 7F   BigSky engage          C3 01   BigSky preset 1
C4 01      SuperSwitcher preset 1
B4 66 00 … B4 71 00   SuperSwitcher Loop/Control params
BF 17 01   ScarlettLove engage    BF 15 7F   ScarlettLove preset Plexi (dict lookup → cc21)
```

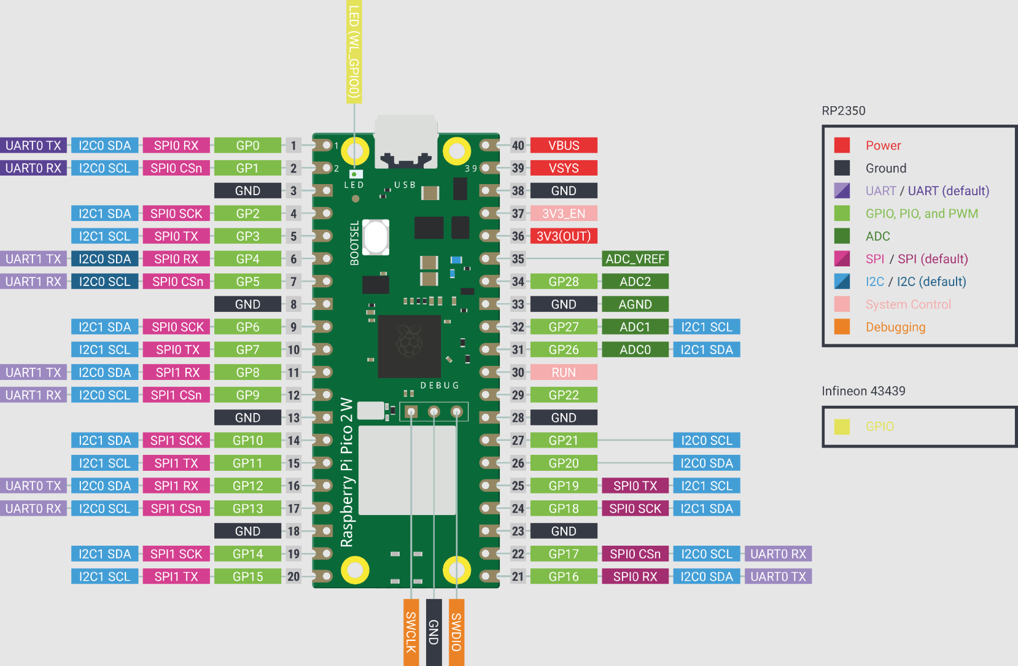
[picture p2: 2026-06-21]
docs/pico_2w_pinout.png

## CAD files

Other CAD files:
pcb/midi-controller/MidiControllerPCB.step

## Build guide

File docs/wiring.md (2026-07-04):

# Wiring — Pico 2 W (RP2350)

This is a **driving-board swap**, not a breadboard build. The MidiController PCB is
unchanged: the Raspberry Pi 4 that used to plug into the board's 40-pin header
(`J35` in `PCB/MidiControllerPCB.sch`) is replaced by a **Pico 2 W**, and the old
ribbon lands on a small adapter that routes each net to the Pico GPIO below.
**The GPIO assignments are defined in
[`include/mc/adapters/mcu/Pins.h`](../include/mc/adapters/mcu/Pins.h) — that header
is the source of truth.** A visual version is in
[`wiring.excalidraw`](wiring.excalidraw) (regenerate with
`python3 tools/gen_wiring_excalidraw.py`). The net-by-net mapping from the Pi's BCM
pins is in [`pi4-pico2w-conversion.md`](pi4-pico2w-conversion.md).

All logic is **3.3 V**. Nothing here is 5 V tolerant — do not feed 5 V into any GPIO.

> ⚠️ **The PCB's own chips run at 5 V, and six of the Pico pins below are inputs
> driven from that 5 V rail.** The board's `VCC` net (originally the Pi's 5 V
> pin, now fed from the Pico's `VBUS`) powers the MCP23017 (`U2`) and the PIC
> MIDI bridge (`U10`), and several passive networks are pulled up to that same
> `VCC` net — confirmed against the schematic netlist
> (`pcb/midi-controller/MidiControllerPCB.net`), not assumed.
>
> | GP | Signal | Why it's 5 V |
> |---|---|---|
> | GP4 | I²C SDA | Pulled to `VCC` by `R74` (4.7 kΩ); driven by `U2`/`U10`, both VDD = `VCC` |
> | GP5 | I²C SCL | Pulled to `VCC` by `R73` (4.7 kΩ); same drivers |
> | GP2 | MCP INT A | Push-pull output from `U2`, powered from `VCC` |
> | GP3 | MCP INT B | Same |
> | GP14 | Encoder A | `R29` (10 kΩ) pulls the switch node to `VCC`, then `R27` (10 kΩ) feeds the GPIO — idles at ~5 V, pulled low on contact closure |
> | GP15 | Encoder B | Same circuit via `R30`/`R28` |
>
> **`VCC` stays at 5 V — don't "fix" this by moving it to `3V3(OUT)`.** `U5`
> (a CD4050 hex buffer, `VCC`-powered) fans the PIC's `MIDI_Tx` line out to
> all 6 jacks; MIDI's current-loop spec is nominally 5 V through 220 Ω
> resistors, so dropping `VCC` to 3.3 V would weaken the current-loop drive to
> real MIDI gear. **Level-shift the Pico side instead** — see §3a below.
>
> The OLED SPI lines (GP17–GP21) are safe as-is — the OLED's `VEE` net is tied
> to `3V3(OUT)` (pin 36), not `VCC`, and the Pico drives those lines rather
> than receiving them.
>
> **The knob RGB LED is also wired to `VCC` (5 V), common-anode** — the
> rotary encoder part (`SW6`, `RGB_Rotary_Enc_PB`) has its LED-common pin 8
> tied to `VCC`, not GND. This doesn't overvolt GP10–GP12 in normal operation
> (the Pico drives those pins, so it controls the voltage rather than the LED
> imposing one), but it does mean the polarity assumed in §3 below and in
> `McuLed` (common-cathode) is backwards for the real board — construct
> `McuLed` with `commonAnode = true`.

---

## 1. What the Pico drives (the 14 ribbon signals)

Everything the Pico touches is one of these. The footswitches and the six MIDI
jacks are **not** wired to the Pico — they hang off the MCP23017 expander and the
PIC MIDI bridge, which the Pico reaches over I²C.

| GP | Pico pin | Peripheral | Signal | Notes |
|-----:|---:|---|---|---|
| GP4  | 6  | I²C0 SDA | shared I²C data | → MCP23017 `0x22` **and** PIC `0x04` |
| GP5  | 7  | I²C0 SCL | shared I²C clock | 400 kHz |
| GP2  | 4  | GPIO in  | MCP INT A | bank-A change (active-high) |
| GP3  | 5  | GPIO in  | MCP INT B | bank-B change |
| GP18 | 24 | SPI0 SCK | OLED SCLK | |
| GP19 | 25 | SPI0 TX  | OLED MOSI | write-only (no MISO) |
| GP17 | 22 | GPIO out | OLED CS | |
| GP20 | 26 | GPIO out | OLED DC | data/command |
| GP21 | 27 | GPIO out | OLED RST | reset |
| GP14 | 19 | GPIO in  | Rotary encoder A | internal pull-up |
| GP15 | 20 | GPIO in  | Rotary encoder B | internal pull-up |
| GP10 | 14 | PWM | Knob LED Red | active-low duty |
| GP11 | 15 | PWM | Knob LED Green | |
| GP12 | 16 | PWM | Knob LED Blue | |

Plus **3V3(OUT) = pin 36**, **VBUS = pin 40** (5 V USB), and **GND** (pins 3, 8, 13,
18, 23, 28, 38). Free for expansion: GP0, GP1, GP6–GP9, GP13, GP16, GP22, GP26–GP28.

> I²C0 is valid on this SDA/SCL pair (SDA on 0/4/8/12/16/20, SCL on 1/5/9/13/17/21);
> SPI0 SCK is valid on GP18 and TX on GP19. Keep these on capable pins if you move
> them in `Pins.h`.

---

## 1a. Level-shifting the 5 V lines (GP2, GP3, GP4, GP5, GP14, GP15)

This bus runs I²C at **400 kHz Fast-mode** (`main_mcu.cpp`: `i2c_init(i2c0,
400'000)`). A generic BSS138 shifter is a passive RC pull-up design — its
low→high rise time depends on pull-up resistance × bus capacitance, and
Fast-mode's 300 ns rise-time budget is routinely missed by that kind of
shifter once a shifter board and adapter wiring add capacitance. So **SDA/SCL
need a real I²C-rated part; the other 4 lines don't** — split the level
shifting across two small parts instead of one:

**SDA/SCL (GP4/GP5) → PCA9306** (or TCA9406) — an active dual-supply I²C/SMBus
voltage-level translator, datasheet-rated for both 100 kHz and 400 kHz:

```
VREF1 → 3.3V (Pico 3V3(OUT), pin 36)     VREF2 → 5V (board VCC)
SDA1  → Pico GP4 (+ 2.2–4.7kΩ pull-up to VREF1)   SDA2 → board SDA node (at R74)
SCL1  → Pico GP5 (+ 2.2–4.7kΩ pull-up to VREF1)   SCL2 → board SCL node (at R73)
GND   → common GND
EN    → tie to VREF1 (3.3V) — do NOT leave floating (chip stays disabled if EN floats)
```

The discrete 3.3V-side pull-ups are still required here even though
`main_mcu.cpp` already calls `gpio_pull_up()` on GP4/GP5 — the Pico's internal
pull-up is a weak ~50–80 kΩ, sized for a slow direct 3.3V bus, not strong
enough to hit Fast-mode's 300 ns rise-time budget. Keep the internal pull
enabled (harmless) but don't rely on it alone; add real 2.2–4.7 kΩ resistors
on SDA1/SCL1. The 5V side keeps its existing `R73`/`R74` — no change there.

**MCP INT A/B + Encoder A/B (GP2, GP3, GP14, GP15) → 4× discrete BSS138,
no added pull-ups.** These are simple sub-1 kHz digital signals (interrupt
edges, encoder clicks) — nowhere near a speed regime where BSS138's RC
charging matters, and `McuInput.cpp` already configures the Pico side with
`gpio_pull_up()` (GP14/GP15) / `gpio_pull_down()` (GP2/GP3). Since these
signals only ever flow board → Pico, that existing internal pull is enough to
terminate the low-voltage side of the shifter — no need to duplicate the
resistor pairs a generic pre-made BSS138 module bundles in. The 5V side is
already terminated too (`R29`/`R30`, and the MCP's own push-pull drive), so
the whole section is just:

```
HV side (5V)                        LV side (3.3V)
─────────────                       ──────────────
GND → board GND                     GND → Pico GND
(no HV or LV supply pin needed — no pull-ups to bias)

BSS138 #1: drain → MCP INT A         source → Pico GP2
BSS138 #2: drain → MCP INT B         source → Pico GP3
BSS138 #3: drain → Encoder A (post-R27 node)   source → Pico GP14
BSS138 #4: drain → Encoder B (post-R28 node)   source → Pico GP15
(gate of all 4 → Pico 3V3(OUT))
```

A passive 2-resistor divider (e.g. 10 kΩ / 15 kΩ → ~3.0 V) per line is an
equally valid alternative to the bare BSS138s for these 4 lines only — just
never use a divider on SDA/SCL, since it can't pull the open-drain bus low
from either side.

`VCC` itself stays sourced from `VBUS` (5 V) as in the pinout table below —
only the Pico-facing side of these 6 signals moves to 3.3 V, through the two
shifters above.

### Parts — where to buy

| Part | Breadboard (THT/module) | PCB (SMD) |
|---|---|---|
| I²C level translator | [SparkFun Level Translator Breakout – PCA9306](https://www.sparkfun.com/sparkfun-level-translator-breakout-pca9306.html) | [PCA9306DCUR](https://www.digikey.com/en/products/detail/texas-instruments/PCA9306DCUR/768359) (VSSOP-8, TI) |
| I²C pull-ups (2.2–4.7 kΩ, on SDA1/SCL1) | included on the breakout above | [RMCF0603FT4K70](https://digikey.com/product-detail/en/RMCF0603FT4K70/RMCF0603FT4K70CT-ND/1943033), 4.7 kΩ, 0603, 1% |
| 4-channel logic level shifter | [Adafruit 4-channel I2C-safe Bi-directional Logic Level Converter (BSS138)](https://www.adafruit.com/product/757) | 4× [BSS138 (onsemi, SOT-23-3)](https://www.digikey.com/en/products/detail/onsemi/BSS138/244210) |

### PCB footprints (KiCad standard library names)

| Part | Package | KiCad footprint |
|---|---|---|
| PCA9306DCUR | VSSOP-8, 3.0×3.0mm, 0.65mm pitch | `Package_SO:VSSOP-8_3.0x3.0mm_P0.65mm` |
| RMCF0603FT4K70 (I²C pull-ups) | 0603 (1608 metric) | `Resistor_SMD:R_0603_1608Metric` |
| BSS138 (onsemi) | SOT-23-3 | `Package_TO_SOT_SMD:SOT-23` |

All three are in KiCad's stock footprint libraries — no download needed.
Double-check the PCA9306DCUR pin-1 orientation against the TI datasheet before
finalizing the silkscreen; VSSOP-8 pin-1 marking conventions vary by
manufacturer.

The Adafruit BSS138 breakout already includes its own 10 kΩ pull-ups on both
sides, which is harmless here even though the discrete-BSS138 SMD design above
doesn't need them — the module is a fine drop-in for breadboarding regardless.

---

## 2. What lives on the (unchanged) PCB, behind the buses

You don't wire these — they're already on the board and the Pico talks to them over
the shared I²C bus. They are configured **exactly** as the Pi configured them.

### MCP23017 expander — I²C `0x22`: footswitches + rotary push button
The 5 footswitches and the rotary encoder's push button are inputs on the expander.
`McpExpander` writes the same register set the Pi did (`Footswitches.py`):
IODIR/GPPU/GPINTEN/INTCON/DEFVAL/IPOL/IOCON. Bit map:

```
bit 0  (A0) = Footswitch 1     bit 8  (B0) = Footswitch 4
bit 1  (A1) = Footswitch 2     bit 10 (B2) = Footswitch 5
bit 2  (A2) = Footswitch 3     bit 15 (B7) = rotary push button (IPOL-inverted)
```

The expander's INT A/B outputs go to GP2/GP3; the firmware reads the bank GPIO over
I²C only when an INT line is asserted (the read clears it). Active-low footswitches
(pressed = 0); the B7 selector is inverted via IPOL so it reads pressed = 1.

### PIC18F26K80 MIDI bridge — I²C `0x04`: all MIDI out
The Pico sends **raw MIDI bytes** to the PIC over I²C (one byte per transaction, like
the Pi's `writeRaw8`). The PIC fans every byte out to all **6 jacks: 2× DIN-5 +
4× TRS-MIDI**. The Pico has no MIDI UART, and the TRS jacks carry **MIDI**, not tempo.

---

## 3. Per-device wiring (the Pico-side peripherals)

### OLED — SSD1306 128×64, SPI0 (7-pin module)
The PCB's OLED header (`J1`) is **7 wires**: the 5 logic lines below plus VEE (power)
and GND. The "4-wire SPI" interface mode = SCLK + MOSI + DC + CS; RST and power are
the other three. All five logic lines are firmware-driven:
```
OLED VEE  → 3V3 (pin 36)        OLED SCLK → GP18 (pin 24)
OLED GND  → GND                 OLED MOSI → GP19 (pin 25)
OLED CS   → GP17 (pin 22)       OLED DC   → GP20 (pin 26)
OLED RST  → GP21 (pin 27)
```
The firmware pulses RST on `begin()`, then drives commands (DC low) and pixel data
(DC high) at 10 MHz. This is the bus the original panel used.

### Rotary encoder — quadrature (the menu knob)
```
Encoder A      → GP14 (pin 19)   — via R27 (10k), pulled up to VCC (5V) by R29 (10k)
Encoder B      → GP15 (pin 20)   — via R28 (10k), pulled up to VCC (5V) by R30 (10k)
Encoder common → GND
```
**Not an internal-pull-up circuit** — the board pulls both lines up to the 5 V
`VCC` net, so they idle at ~5 V and pull low on contact closure. Route both
through the level shifter in §1a before wiring to the Pico. 4 quadrature steps
per detent (`kStepsPerDetent = 4`). **The push button is not here** — it's MCP
bit B7, read over I²C with the footswitches.

### Knob RGB LED — PWM, common-anode (confirmed on the real board)
```
GP10 → 220–470 Ω → LED Red cathode
GP11 → 220–470 Ω → LED Green cathode
GP12 → 220–470 Ω → LED Blue cathode
LED common anode → VCC (5V)
```
The encoder part's LED-common pin is tied to the board's `VCC` net (5 V), not
GND — confirmed in the schematic netlist. Construct `McuLed` with
`commonAnode = true` (lower duty = brighter). This doesn't overvolt the GPIOs
in normal operation since the Pico actively drives GP10–GP12 rather than the
LED imposing a voltage, but it does mean the common-cathode assumption in
earlier versions of this doc was backwards for the real hardware.

### Shared I²C bus
```
GP4 (SDA) and GP5 (SCL) → MCP23017 (0x22) and PIC bridge (0x04), in parallel
GP2 ← MCP INT A          GP3 ← MCP INT B
```
The board already has 4.7 kΩ pull-ups on SDA/SCL (`R73`/`R74`) — to `VCC`
(5 V), not 3V3. Route all four lines (SDA, SCL, INT A, INT B) through the
level shifter in §1a; don't add a second set of 3V3 pull-ups on top of the
board's existing ones.

---

## 4. Quick pinout (physical board, USB at top)

```
                ┌───────────  USB  ───────────┐
              ──┤ 1  GP0            VBUS  40 ├──  5V (USB)
              ──┤ 2  GP1            VSYS  39 ├──
         GND  ──┤ 3  GND            GND   38 ├──  GND
   MCP INT A  ──┤ 4  GP2          3V3_EN  37 ├──
   MCP INT B  ──┤ 5  GP3        3V3(OUT)  36 ├──  3.3V → peripherals
    I2C SDA   ──┤ 6  GP4       ADC_VREF   35 ├──
    I2C SCL   ──┤ 7  GP5            GP28  34 ├──
         GND  ──┤ 8  GND            AGND  33 ├──
              ──┤ 9  GP6            GP27  32 ├──
              ──┤ 10 GP7            GP26  31 ├──
              ──┤ 11 GP8             RUN  30 ├──
              ──┤ 12 GP9            GP22  29 ├──
         GND  ──┤ 13 GND            GND   28 ├──  GND
   LED Red    ──┤ 14 GP10           GP21  27 ├──  OLED RST
   LED Green  ──┤ 15 GP11           GP20  26 ├──  OLED DC
   LED Blue   ──┤ 16 GP12           GP19  25 ├──  OLED MOSI
              ──┤ 17 GP13           GP18  24 ├──  OLED SCLK
         GND  ──┤ 18 GND            GND   23 ├──  GND
   Encoder A  ──┤ 19 GP14           GP17  22 ├──  OLED CS
   Encoder B  ──┤ 20 GP15           GP16  21 ├──
                └─────────────────────────────┘
```

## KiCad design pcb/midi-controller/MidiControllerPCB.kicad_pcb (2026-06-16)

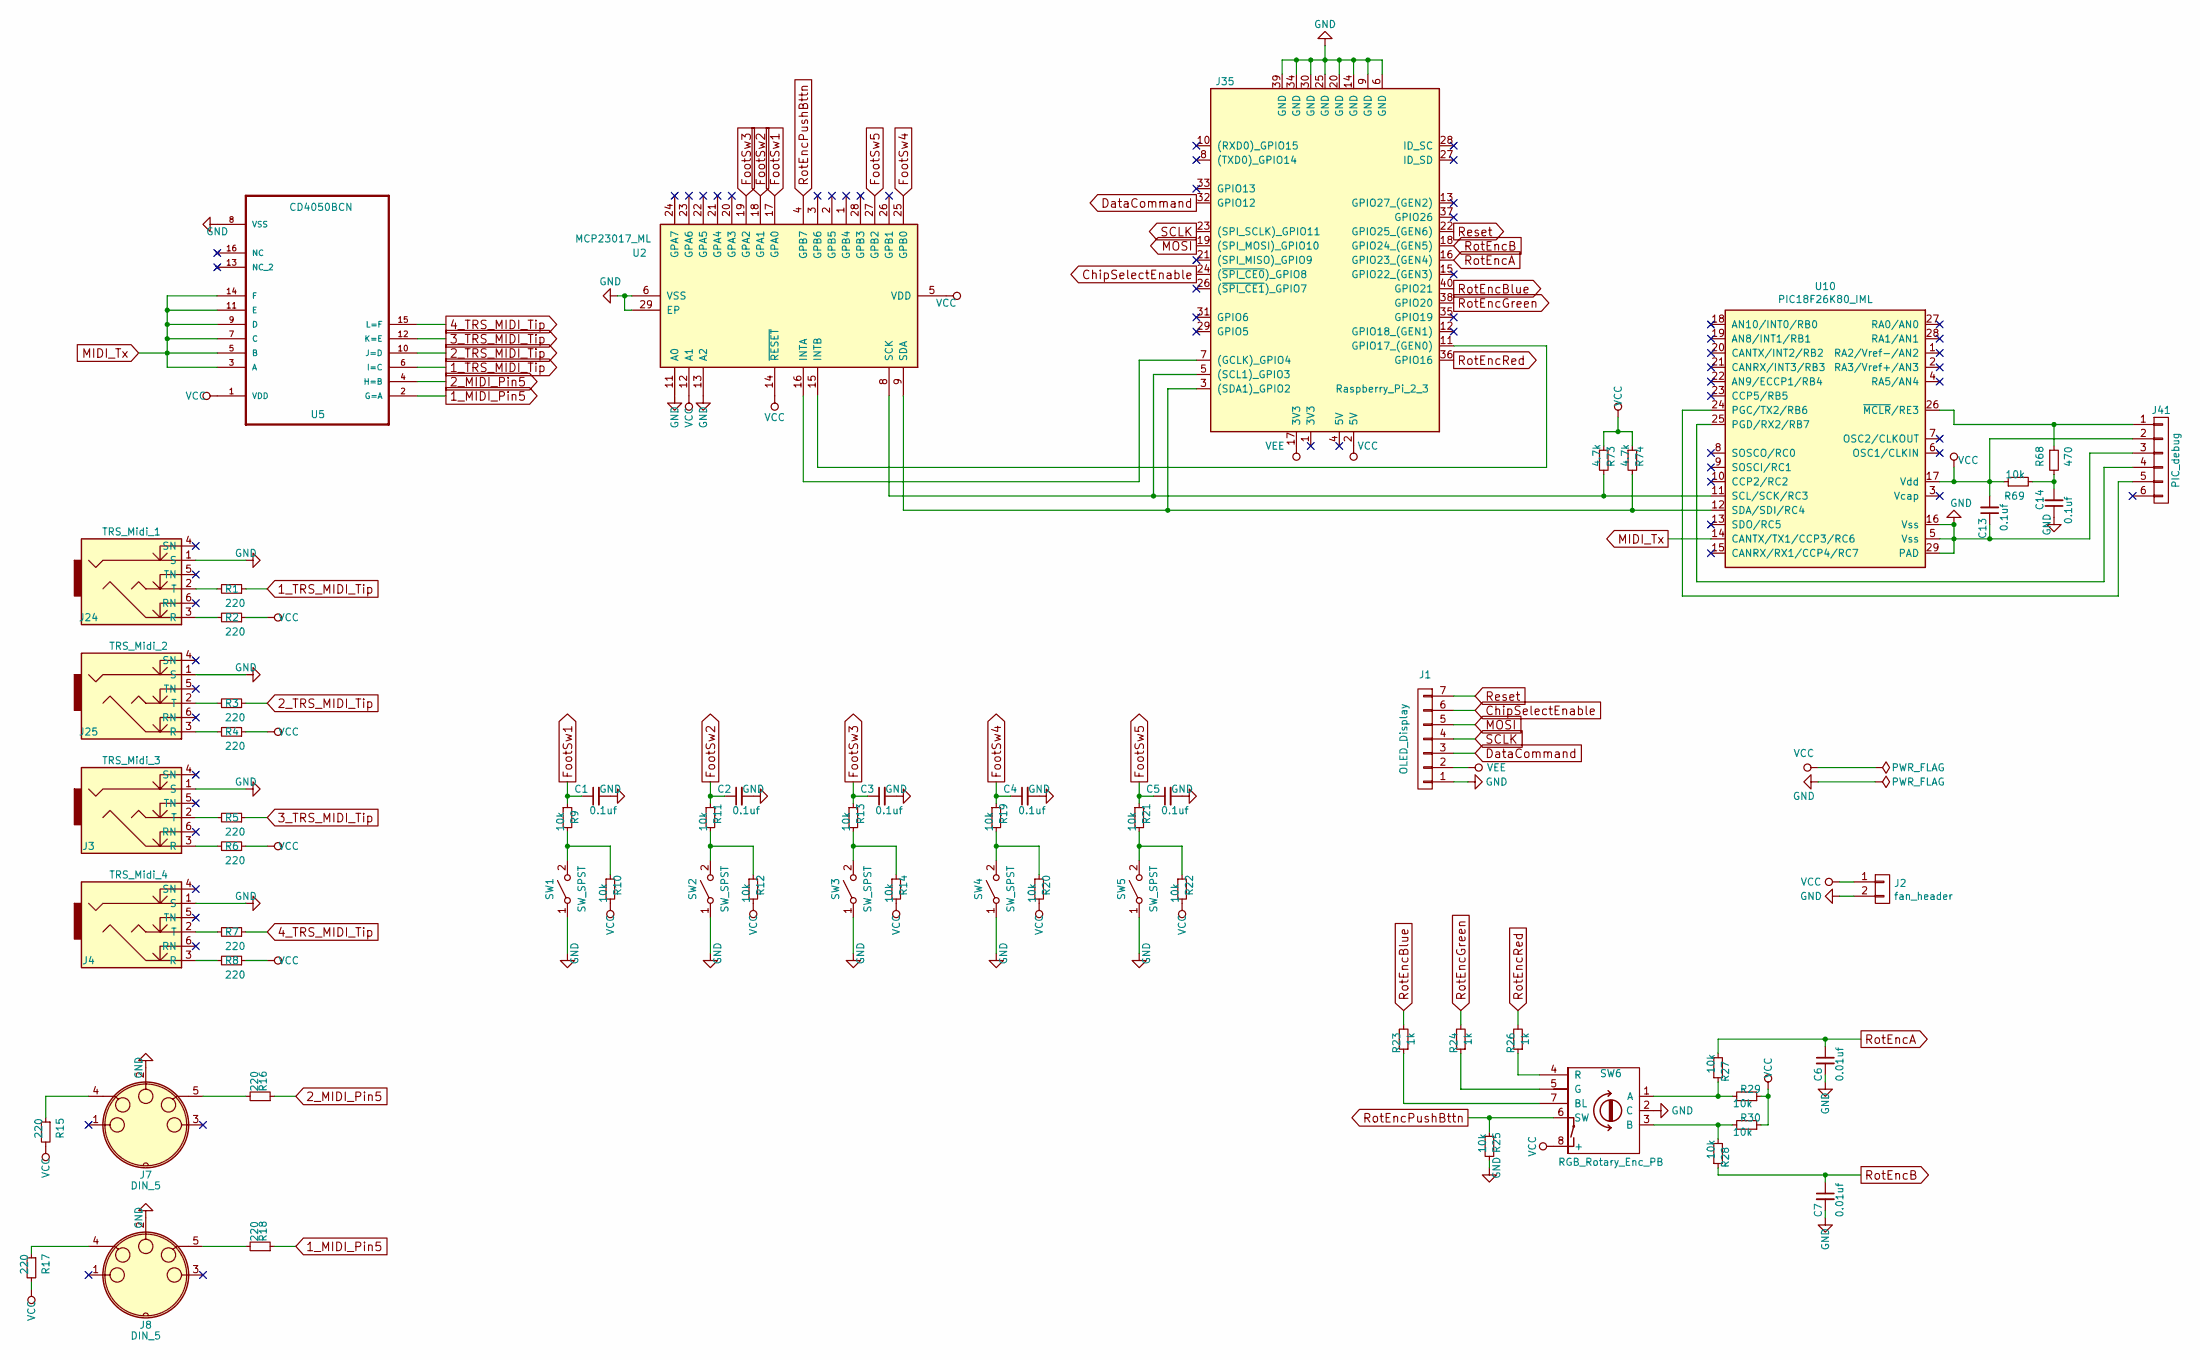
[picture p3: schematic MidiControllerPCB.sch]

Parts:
C1, C2, C3, C4, C5, C13, C14: 0.1uf; C_1206_HandSoldering
C6, C7: 0.01uf; C_1206_HandSoldering
J1: OLED_Display; Pin_Header_Straight_1x07_Pitch1.27mm
J2: fan_header; Pin_Header_Straight_1x02_Pitch2.54mm
J3: TRS_Midi_3; NRJ6HM-1-PRE
J4: TRS_Midi_4; NRJ6HM-1-PRE
J7, J8: DIN_5; Midi-Connector
J24: TRS_Midi_1; NRJ6HM-1-PRE
J25: TRS_Midi_2; NRJ6HM-1-PRE
J35: Raspberry_Pi_2_3; Pin_Header_Straight_2x20_Pitch2.54mm
J41: PIC_debug; Pin_Header_Straight_1x06_Pitch2.54mm
R1, R2, R3, R4, R5, R6, R7, R8, R15, R16, R17, R18: 220; R_1206_HandSoldering
R9, R10, R11, R12, R13, R14, R19, R20, R21, R22, R25, R27, R28, R29, R30, R69: 10k; R_1206_HandSoldering
R23, R24, R26: 1k; R_1206_HandSoldering
R68: 470; R_1206_HandSoldering
R73, R74: 4.7k; R_1206_HandSoldering
SW1, SW2, SW3, SW4, SW5: SW_SPST; Pin_Header_Straight_1x02_Pitch2.54mm
SW6: RGB_Rotary_Enc_PB; Pin_Header_Straight_2x04_Pitch2.54mm
U2: MCP23017_ML; QFN-28-1EP_6x6mm_Pitch0.65mm
U5: CD4050BCN; TSSOP-16_4.4x5mm_Pitch0.65mm
U10: PIC18F26K80_IML; QFN-28-1EP_6x6mm_Pitch0.65mm

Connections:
1_MIDI_Pin5: R18.1, U5.2 (G=A)
1_TRS_MIDI_Tip: R1.1, U5.6 (I=C)
2_MIDI_Pin5: R16.1, U5.4 (H=B)
2_TRS_MIDI_Tip: R3.1, U5.10 (J=D)
3_TRS_MIDI_Tip: R5.1, U5.12 (K=E)
4_TRS_MIDI_Tip: R7.1, U5.15 (L=F)
ChipSelectEnable: J1.6, J35.24 ((~SPI_CE0~)_GPIO8)
DataCommand: J1.3, J35.32 (GPIO12)
FootSw1: C1.1, R9.1, U2.17 (GPA0)
FootSw2: C2.1, R11.1, U2.18 (GPA1)
FootSw3: C3.1, R13.1, U2.19 (GPA2)
FootSw4: C4.1, R19.1, U2.25 (GPB0)
FootSw5: C5.1, R21.1, U2.27 (GPB2)
GND: C1.2, C2.2, C3.2, C4.2, C5.2, C6.2, C7.2, C13.1, C14.1, J1.1, J2.2, J3.1 (S), J4.1 (S), J7.2, J8.2, J24.1 (S), J25.1 (S), J35.6 (GND), J35.9 (GND), J35.14 (GND), J35.20 (GND), J35.25 (GND), J35.30 (GND), J35.34 (GND), J35.39 (GND), J41.3, R25.2, SW1.1 (A), SW2.1 (A), SW3.1 (A), SW4.1 (A), SW5.1 (A), SW6.2 (C), U2.6 (VSS), U2.11 (A0), U2.13 (A2), U2.29 (EP), U5.8 (VSS), U10.5 (Vss), U10.16 (Vss), U10.29 (PAD)
MIDI_Tx: U5.3 (A), U5.5 (B), U5.7 (C), U5.9 (D), U5.11 (E), U5.14 (F), U10.14 (CANTX/TX1/CCP3/RC6)
MOSI: J1.5, J35.19 ((SPI_MOSI)_GPIO10)
unnamed: C14.2, R68.2, R69.2
unnamed: J3.2 (T), R5.2
unnamed: J3.3 (R), R6.2
unnamed: J4.2 (T), R7.2
unnamed: J4.3 (R), R8.2
unnamed: J7.4, R15.1
unnamed: J7.5, R16.2
unnamed: J8.4, R17.1
unnamed: J8.5, R18.2
unnamed: J24.2 (T), R1.2
unnamed: J24.3 (R), R2.2
unnamed: J25.2 (T), R3.2
unnamed: J25.3 (R), R4.2
unnamed: J35.3 ((SDA1)_GPIO2), R74.2, U2.9 (SDA), U10.12 (SDA/SDI/RC4)
unnamed: J35.5 ((SCL1)_GPIO3), R73.2, U2.8 (SCK), U10.11 (SCL/SCK/RC3)
unnamed: J35.7 ((GCLK)_GPIO4), U2.16 (INTA)
unnamed: J35.11 (GPIO17_(GEN0)), U2.15 (INTB)
unnamed: J41.1, R68.1, U10.26 (~MCLR~/RE3)
unnamed: J41.4, U10.25 (PGD/RX2/RB7)
unnamed: J41.5, U10.24 (PGC/TX2/RB6)
unnamed: R9.2, R10.1, SW1.2 (B)
unnamed: R11.2, R12.1, SW2.2 (B)
unnamed: R13.2, R14.1, SW3.2 (B)
unnamed: R19.2, R20.1, SW4.2 (B)
unnamed: R21.2, R22.1, SW5.2 (B)
unnamed: R23.1, SW6.7 (BL)
unnamed: R24.1, SW6.5 (G)
unnamed: R26.1, SW6.4 (R)
unnamed: R27.1, R29.2, SW6.1 (A)
unnamed: R28.2, R30.2, SW6.3 (B)
Reset: J1.7, J35.22 (GPIO25_(GEN6))
RotEncA: C6.1, J35.16 (GPIO23_(GEN4)), R27.2
RotEncB: C7.1, J35.18 (GPIO24_(GEN5)), R28.1
RotEncBlue: J35.40 (GPIO21), R23.2
RotEncGreen: J35.38 (GPIO20), R24.2
RotEncPushBttn: R25.1, SW6.6 (SW), U2.4 (GPB7)
RotEncRed: J35.36 (GPIO16), R26.2
SCLK: J1.4, J35.23 ((SPI_SCLK)_GPIO11)
VCC: C13.2, J2.1, J35.2 (5V), J41.2, R2.1, R4.1, R6.1, R8.1, R10.2, R12.2, R14.2, R15.2, R17.2, R20.2, R22.2, R29.1, R30.1, R69.1, R73.1, R74.1, SW6.8 (+), U2.5 (VDD), U2.12 (A1), U2.14 (~RESET~), U5.1 (VDD), U10.17 (Vdd)
VEE: J1.2, J35.17 (3V3)

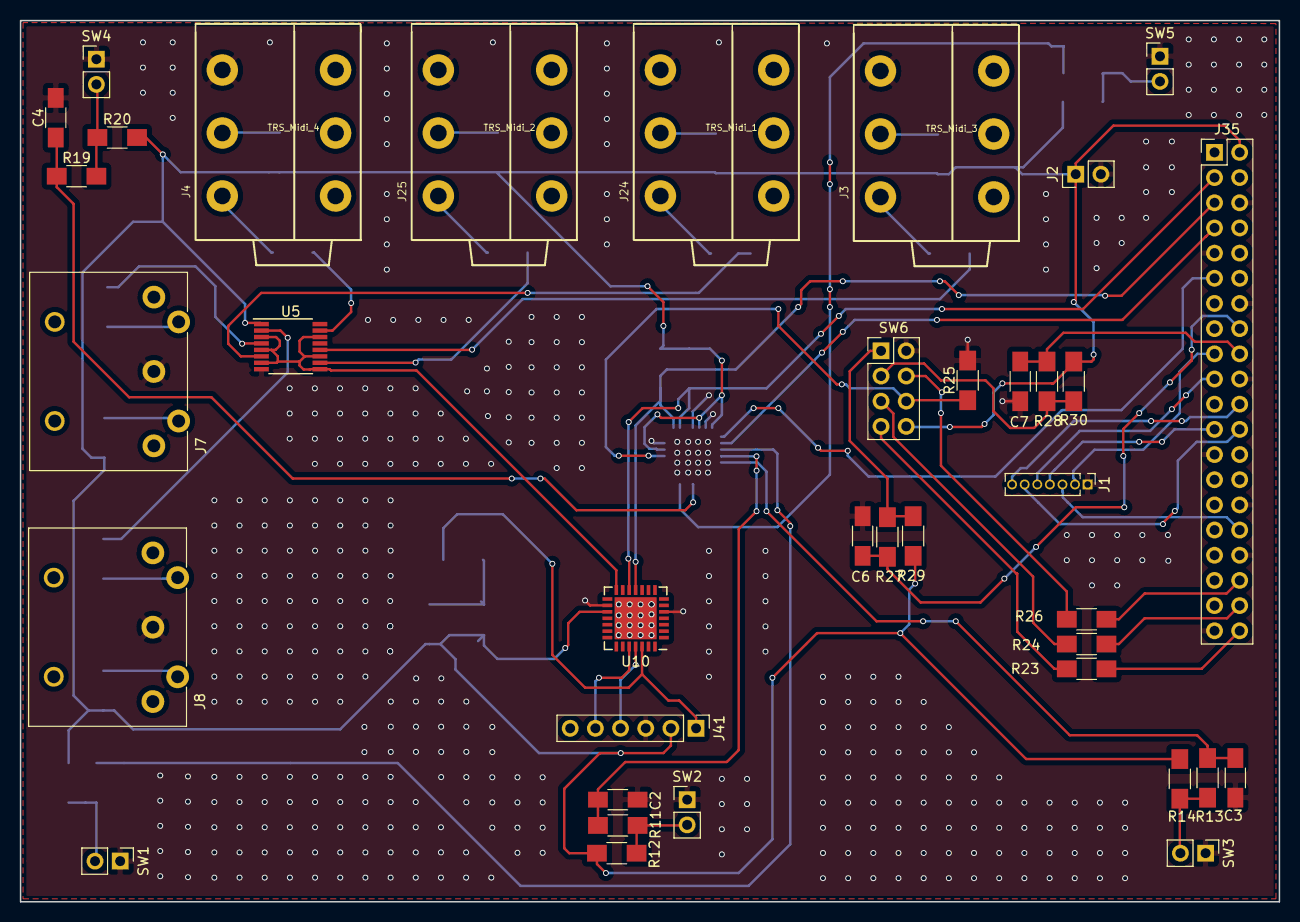
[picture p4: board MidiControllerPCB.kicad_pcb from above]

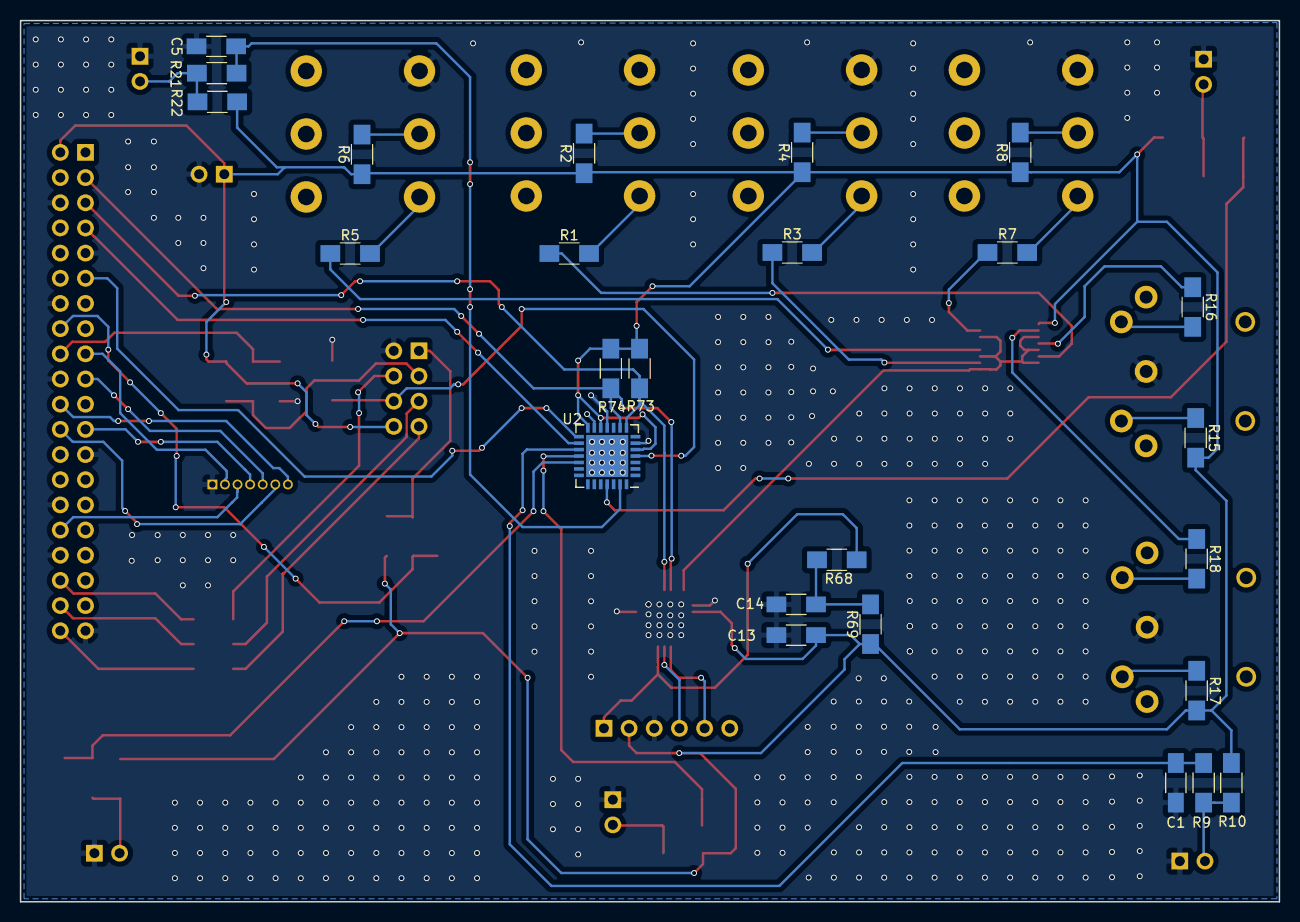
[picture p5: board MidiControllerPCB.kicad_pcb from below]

Board: 2 copper layers, 127.0 x 88.9 mm, 62 parts (25 on the bottom side), 56 nets.

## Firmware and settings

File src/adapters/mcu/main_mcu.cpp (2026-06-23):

// Firmware entry point for the Pico 2 W (RP2350). Wires the MCU adapters to the
// same domain core the desktop sim uses, then runs its own poll loop.
//
// Note: it does NOT call Application::run() — that loop stops when input.poll()
// returns false, which is the right contract for scripted desktop input but not
// for a real-time device. Here poll() returns false simply means "no event yet".
#include <cstdio>

#include "hardware/flash.h"  // FLASH_SECTOR_SIZE, PICO_FLASH_SIZE_BYTES
#include "hardware/watchdog.h"
#include "pico/stdlib.h"
#include "pico/unique_id.h"  // pico_get_unique_board_id_string

#include "hardware/i2c.h"
#include "hardware/spi.h"

#include "mc/adapters/mcu/EmbeddedData.h"
#include "mc/adapters/mcu/Log.h"
#include "mc/adapters/mcu/FlashKv.h"
#include "mc/adapters/mcu/McpExpander.h"
#include "mc/adapters/mcu/McuClock.h"
#include "mc/adapters/mcu/McuConfigStore.h"
#include "mc/adapters/mcu/McuInput.h"
#include "mc/adapters/mcu/McuLed.h"
#include "mc/adapters/mcu/LedPulse.h"
#include "mc/adapters/mcu/McuMidiOut.h"
#include "mc/adapters/mcu/McuSystemControl.h"
#include "mc/adapters/mcu/Pins.h"
#include "mc/adapters/mcu/Ssd1306Display.h"
#include "mc/adapters/mcu/WifiManager.h"
#include "mc/app/Application.h"
#include "mc/app/EditorProtocol.h"
#ifdef MC_ENABLE_USB_EDITOR
#include "mc/adapters/mcu/UsbConfigTransport.h"  // raw USB vendor link (WinUSB), stdio on UART
#else
#include "mc/adapters/mcu/StdioConfigTransport.h"  // editor link over the stdio USB CDC
#endif

using namespace mc;
using namespace mc::mcu;

int main() {
    stdio_init_all();
    LOG_I("boot", "stdio ready");

    if (watchdog_caused_reboot()) {
        LOG_W("boot", "recovered from a watchdog hang");
    }

    McuClock clock;

    // Shared I2C bus (i2c0): the MCP23017 expander (0x22) and the PIC MIDI bridge
    // (0x04) both live here, exactly as on the Pi's single I2C bus. Bring it up once.
    i2c_init(i2c0, 400'000);
    gpio_set_function(pins::I2C_SDA, GPIO_FUNC_I2C);
    gpio_set_function(pins::I2C_SCL, GPIO_FUNC_I2C);
    gpio_pull_up(pins::I2C_SDA);
    gpio_pull_up(pins::I2C_SCL);
    LOG_I("boot", "I2C bus up at 400 kHz (SDA=GP%u SCL=GP%u)", pins::I2C_SDA, pins::I2C_SCL);

    McuMidiOut midi(i2c0, pins::MIDI_PIC_ADDR);  // raw MIDI -> PIC -> 6 jacks
    McpExpander expander(i2c0, pins::MCP23017_ADDR);
    Ssd1306Display display(spi0, pins::OLED_SCLK, pins::OLED_MOSI, pins::OLED_CS, pins::OLED_DC,
                           pins::OLED_RST);
    McuLed led(pins::LED_R, pins::LED_G, pins::LED_B, /*commonAnode=*/true);
    McuInput input(clock, expander, pins::FOOTSWITCH_BITS, 5, pins::SELECTOR_BIT, pins::MCP_INT_A,
                   pins::MCP_INT_B, pins::ENCODER_A, pins::ENCODER_B);
    // Persist "save defaults" in the last flash sector (survives reboot).
    FlashKv persist(PICO_FLASH_SIZE_BYTES - FLASH_SECTOR_SIZE, FLASH_SECTOR_SIZE);
    McuConfigStore store(kEmbeddedData, kEmbeddedDataCount, &persist);

    LOG_I("boot", "display begin");
    display.begin();   // bring up the OLED FIRST so a stuck I2C bus can't keep it dark
    LOG_I("boot", "expander begin");
    expander.begin();
    LOG_I("boot", "led begin");
    led.begin();

    // The Application drives the rig; the loop also services the editor link over
    // the USB CDC. (Transport isn't passed to the Application — we run the loop.)
    Application app({&store, &midi, &display, &led, &clock, &input, nullptr});
    LOG_I("boot", "app setup");
    app.setup();

    // WiFi: connects to a saved network on boot; the editor link also runs over
    // TCP (same protocol) + mDNS. Credentials are set over USB the first time.
    WifiManager wifi(store);
    wifi.setStatusSink([&display](const std::string& s) { display.setMessage(s); });

    McuSystemControl sys;  // reboot / BOOTSEL on editor command
    EditorProtocol protocol(store, app, &wifi, &sys);

    // Surface the RP2350 board id in `identify` so the editor can tell units apart
    // and dedupe the same device seen over both USB and WiFi.
    char boardId[2 * PICO_UNIQUE_BOARD_ID_SIZE_BYTES + 1];
    pico_get_unique_board_id_string(boardId, sizeof(boardId));
    protocol.setDeviceId(boardId);
    LOG_I("boot", "board id: %s", boardId);

    wifi.setProtocol(&protocol);

#ifdef MC_ENABLE_USB_EDITOR
    UsbConfigTransport transport(protocol);  // raw USB vendor link (WinUSB)
    LOG_I("boot", "transport: raw USB vendor (WinUSB)");
#else
    StdioConfigTransport transport(protocol);  // USB CDC link
    LOG_I("boot", "transport: stdio USB CDC");
#endif
    transport.begin();
    LOG_I("boot", "wifi begin");
    wifi.begin();  // CYW43 init + auto-connect if a known network is enabled

    // input.begin() must come AFTER wifi.begin(): cyw43_arch_init installs the SDK's
    // GPIO dispatch handler for IO_IRQ_BANK0. gpio_add_raw_irq_handler_masked (used
    // by the encoder IRQ) is called by that dispatcher — registering before it exists
    // means the handler never fires. Moving here also lets the selector pin (no pull-up,
    // active-high) fully settle from any boot-time capacitive transient before we latch
    // the initial level[] state from exp_.readGpio().
    LOG_I("boot", "input begin");
    input.begin();

    // Onboard LED blips ~50ms on every handled input/command. Safe to drive only
    // after wifi.begin() has run cyw43_arch_init (the LED is on the CYW43 chip).
    LedPulse activityLed(50);
    app.setActivitySink([&activityLed] { activityLed.trigger(); });

    // DIAGNOSTIC: blink the onboard LED on every raw encoder-pin edge, BEFORE any
    // quadrature decoding. Turning the knob should blink the LED iff GP14/GP15 are
    // actually moving and the IRQ is firing — this splits a wiring/IRQ fault (no
    // blink) from a decode fault (blinks but no menu movement). Remove once the
    // encoder is confirmed working.
    input.setEncoderEdgeDebug([&activityLed] { activityLed.trigger(); });

    // Enable the hardware watchdog only after the (potentially slow) boot init is
    // done. Any single loop iteration that hangs > 8 s reboots the device. The
    // longest in-loop work — a ~30 KB get_pedal parse/stream or a debounced flash
    // write — is well under that, and WiFi is serviced non-blocking in poll().
    watchdog_enable(8000, /*pause_on_debug=*/true);
    LOG_I("boot", "watchdog armed 8s — entering main loop");

    InputEvent ev;
    while (true) {
        watchdog_update();
        while (input.poll(ev)) app.handleEvent(ev);

        transport.poll();
        wifi.poll();
        display.tick(clock.now());  // drive the title marquee
        activityLed.update();       // clear the activity blip after its window
        app.tick();  // debounced "save defaults" flush, off the input path
        sys.poll();  // performs a scheduled reboot/BOOTSEL once the ack has flushed
        tight_loop_contents();
    }
}

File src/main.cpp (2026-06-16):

// Sim entry point. Boots the core from data/ and runs a scripted sequence of
// footswitch / encoder / rotary events, logging every MIDI message, LED
// update and OLED line — the desktop stand-in for the real pedal.
#include <iostream>

#include "mc/adapters/sim/FsConfigStore.h"
#include "mc/adapters/sim/SimAdapters.h"
#include "mc/app/Application.h"

int main() {
    using namespace mc;

    sim::FsConfigStore store("data");
    sim::LoggingMidiOut midi;
    sim::ConsoleDisplay display;
    sim::LoggingLed led;
    sim::ChronoClock clock;
    sim::NullConfigTransport transport;

    // Deterministic demo script (no stdin needed).
    sim::ScriptedInput input;
    input.footswitchLong(3)    // "Select Part Up": jump to Bridge and load it
        .footswitchShort(1)    // "Part Dn": preview Chorus
        .footswitchShort(2)    // "Select": load Chorus
        .footswitchShort(5)    // "Song Up": preview next song
        .footswitchShort(2)    // "Select": load next song's first part
        .rotaryPress(0.2)      // rotary short press: enter Setup menu
        .encoderCW()           // Setup -> Songs
        .encoderCW()           // Setup -> Parts
        .rotaryPress(0.2)      // enter Parts list
        .encoderCW()           // highlight next part
        .rotaryPress(0.2);     // select it -> load that part

    Application app({&store, &midi, &display, &led, &clock, &input, &transport});

    std::cout << "=== MidiController sim: boot from data/ ===\n";
    app.setup();
    std::cout << "=== running scripted input ===\n";
    app.run();
    std::cout << "=== done ===\n";
    return 0;
}

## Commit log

2026-06-14 Integrate/bare metal pico 2w (#1)
    * Add C++ MidiController firmware: domain core, sim, tests, Pico 2 W scaffold
    Port the Raspberry Pi Python "brain" to a portable, hardware-free C++17 core
    behind ports & adapters. MIDI output matches the Python byte-for-byte
    (including its cc:0 "bank select" quirk).
    - domain: MidiMessage, Value, Transform (safe parser, no eval/regex),
    PedalConfig, MidiPedal dispatch, Setlist/Song/Part, ButtonSM, ControllerState,
    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
2026-06-14 Update flashing instructions for Pico 2 W to clarify initial setup and BOOTSEL process
2026-06-16 add midicontroller pcb
    [LooperPCB-2019-08-03-11-41-35.sch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]
2026-06-16 Refactor Pico 2 W firmware to drive the real PCB (MCP23017 over I²C, MIDI via PIC bridge, SPI OLED) and remove the fictional tempo-output port
2026-06-16 Remove cooling fan from Pico 2 W conversion documentation, clarifying that the RP2350 runs cold and requires no active cooling.
2026-06-21 Add script to convert BDF fonts to C++ header with bitmap data
    This commit introduces a new Python script, `bdf_to_header.py`, which converts monospace BDF fonts into a C++ header file containing fixed-cell bitmap representations. The script parses the BDF format, extracts glyph data, and generates a header file suitable for use in C++ projects. The generated header includes a structure for bitmap fonts and methods to access glyph data based on ASCII values. The script supports multiple font sizes and ensures compatibility with printable ASCII characters (0x20 to 0x7E).
    [McpExpander.cpp, McuInput.cpp, McuInput.h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]
2026-06-21 Refactor MCP expander and input handling for improved encoder and button state management
2026-06-23 Refactor encoder handling for improved state management and debounce logic; optimize display message rendering to prevent unnecessary redraws
    [McuInput.cpp, McuInput.h, main_mcu.cpp]
2026-07-04 Add on-device pedal editor with lazy loading for MIDI parameters and actions
2026-07-04 Update wiring and power supply documentation for Pico 2 W integration; clarify 5V signal handling and level-shifting requirements
